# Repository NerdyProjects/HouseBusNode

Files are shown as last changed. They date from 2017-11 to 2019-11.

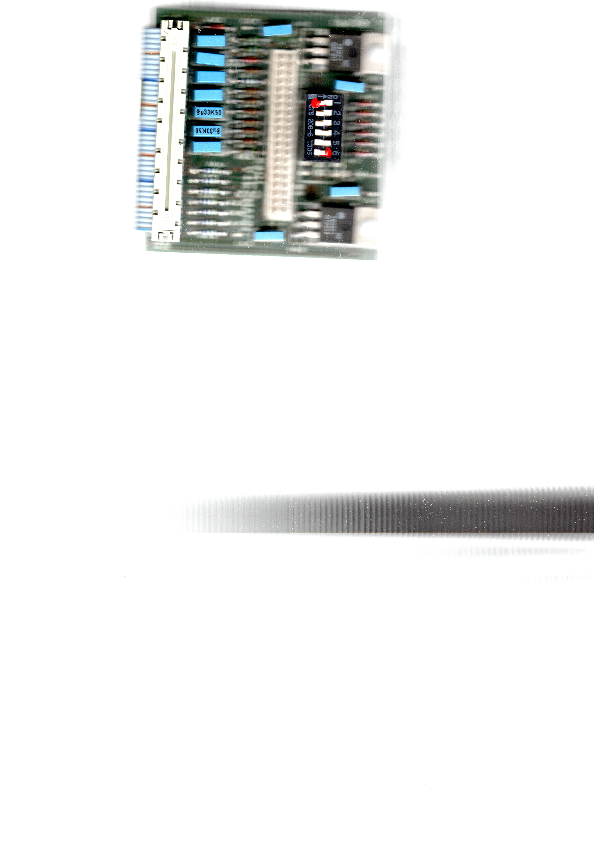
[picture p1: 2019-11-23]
viessmann_trimatik_elektronikbox.jpg

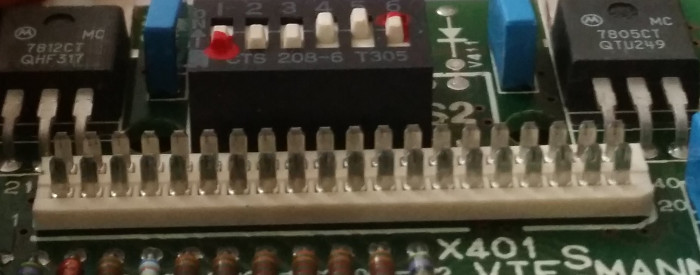
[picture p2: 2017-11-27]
viessmann_stecker.jpg

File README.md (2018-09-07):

# Hausbus Spielerei

## Short introduction

This repository holds hardware and software design for a work in progress house bus system.
It operates using a 4-wire bus using the CAN bus as well as supply of ~10 - 20 V.
It should provide a base for very simple nodes (e.g. sensors, digital actors) as well as more complex nodes (e.g. a heating system controller).

## Background

The system design started in November 2017 when the need of a better heating system controller arose in a housing project in Wurzen, Germany.
The gas heating system, a well overpowered Viessmann Atola controlled by a Viessmann Trimatik MC should be better controlled in light load conditions with options to get it better tuned to the actual needs.
A good heating system needs to be remote controllable as well as take a lot of different control inputs, in best case from every room as well as every radiator and maybe even some valves in between.

Additionally, it is nice to gather statistics about used gas, electricity and water.

When such a system is in place already, it would be great to combine it with other actors and sensors around the house: Doorbell, switches, PIR sensors, dimming of lights (without having to use expensive dimmers or even without standing up from your desk).

## Design implications

The design is driven by a mind that likes to play around with technology, gather statistics and try to optimize the world around.
The design is not meant to be used for things that require absolute reliability or fool-saveness.
The design is not meant to be used in applications or environment where security is needed.
The communication between the nodes happen without any security layer: Every node is able to set any value in any other node, so can everybody tapping into the bus wire.

# Hardware description

## PCB Errata

## Mini-PCB

* Triac T1/T2 (Pin 1/2) need to be exchanged. Easiest to be done by soldering Triac backwards just with Pin 1 and 2 and using a wire for Pin 3.

## Microcontroller

The microcontroller in use is the STM32F072RBT6. It is powered by an ARM Cortex-M0 core with 128 kBytes of flash memory and 16 kBytes of SRAM data memory.

### Compatible boards/projects

There is a list of boards using the same controller.
Because of the broad availability and use of these boards, they might be worth a look for application examples (be it hardware or software).

* STM32F072 Discovery Kit
* STM32 Nucleo-64 / Nucleo-F072RB (Arduino like development board)

## BUS

The CAN-Bus is not meant to operate with long stub lines - but using slew rate control, it is safe to do so.
Following CAN physical layer requirements (TI SLLA270, 01/2008), the maximum stub length should be less than 1/3rd of the critical length, which equals the down-and-back delay of the transition time, which is the longer of the rise or fall times:

| HVD230 Rs | Tplh | Tphl | 1/3 of critical length | max. length @ 250 kBaud | max. length @ 125 kBaud |
| --- | ---- | ---- | --- | --- | --- |
| 0 | 35 ns| 70 ns | 2.3 m (1.1 m) | ~280 m |
| 10k | 65 ns| 130 ns | 4.3 m (2.1 m) | ~282 m |
| 100k | 500 ns| 870 ns | 29 m (16.6 m) | ~208 m |

The max. length is calculated using the HVD230 given tp of ~37 ns, the comparator delay inside the processor is estimated with 10 ns.
The calculation shows, that the effect of slew rate control on bus length is minimal for these speeds.
At a higher speed, the transition delay inside the driver takes up bigger parts of the available time window, which is ~3 us for 250 kBaud.
Also, it is not exactly clear to me why the speed does not matter when calculating the stub lengths, but the given results clearly show, that 100k slew rate control and a 250 kBaud bus is appropriate for usage in a house.
For a normal sized living house, the bus should be fed through each flats hallway to allow each rooms' connection with stubs.
For houses like the housing project where this is designed for, this leads to a bus length of approximately 120m:
Both ends "stub" 30m each, 2 times 3 floors with 3.5 m height (connection just through stubs, as all points are reachable within 30m), 2 times basement to pass to the next building (15m), which sums up to 30+30+2\*3\*3.5+15+15 = 111m

## Power

Each bus node has an on-board step down converter to convert the bus voltage (because of the availabiliy of cheap step downs <24 V) to 3.3 V for the circuit.
Some applications might use the bus power directly, when exact voltage does not matter and current is limited (so the bus is not powered off).
The network should be usable with ~50 nodes that can be power-fed at multiple times in the bus.

The bus cable resistance following the above approximation (120m) and taking 0.4mm/0.13mm² cable (AWG26) as a worst case candidate comes down to ~30 ohms.
Taking a worst case, default active operational current of 50 mA @ 3.3V for 50 nodes (~8 W), as well as a supply of 18 V already results in a current consumption of 450 mA, which would be too big for the given cabling.
Due to this, power consumption of nodes should be kept in mind when deploying them.

A node that is close to a powerful bus power feed can easily use the bus power to drive lighting or a doorbell with 20 W.
It is left to the deployer of the bus system to ensure that the bus voltage drop is taken into account when deploying powerful nodes.

## Board pin mapping (Board: Hausspielerei 11/2017)

Please always consider the schematics for details.
Still, the following table describes the available connectors, suggested use cases and possible use cases.

### Analog IO

Analog pins on this board are named with their corresponding usage on the Viessmann Trimatik-MC.
All of the pins in the list feature strong pullup resistors, that are all switched by /PA0 (Q1) to AVCC (3,3V)

| pin name | controller pin | available hardware | possible alternative functions |
| --- | --- | --- | --- |
| IN\_ATS  | PA1 | series 0805, 2x 0805 to GND | USART2\_RTS / RS422 DE / RS485 DE, USART4\_RX |
| IN\_KTS  | PA2 | 0805 to GND | USART2\_TX / RS422 TX / RS485 TX, COMP1\_INP, COMP2\_INM, COMP2\_OUT |
| IN\_VTS  | PA3 | 0805 to GND | USART2\_RX / RS422 RX / RS485 RX, COMP2\_INP |
| IN\_STS  | PA4 | 0805 to GND | COMP2\_INM, COMP1\_INM, DAC_OUT1 |
| IN\_FB1  | PA5 | 0805 to GND | COMP1\_INM, COMP2\_INM, DAC_OUT2, SPI1\_SCK |  
| IN\_FB2  | PA6 | 0805 to GND | COMP1\_OUT, SPI1\_MISO |
| LED_A | PA7 | series 0805 | COMP2\_OUT, SPI1\_MOSI |

### Connectors

| Connector  | Pins | controller pins | primary purpose | alternative purposes | conflicting with |
| --- | ---  | --- | --- | --- | ---  |
| J12, J13 | VCC GND CANH CANL | | Power (5-24V), bus + passthrough | | No conflicts |
| SMPS (J3)  | NC Vin(J12/13 Vcc) GND 3,3V | | SMPS module for 3,3V power supply | | No conflicts |
| RS485 (J17)| GND A B 3,3V | PA1, PA2, PA3 | RS485/RS422 connection to sub boards | By bridging appropriate Pins in U1, it can be used as USART2 TX/RX/RTS or Analog inputs | DE: J9 / IN\_ATS |
| J9 | IN\_FB1 3,3V GND IN\_ATS | PA5, PA1 | digital/analog input for hall sensor module | | IN\_ATS: RS485 DE |
| D1 (LED A) | GND LED\_A | PA7 | General purpose LED | IO, Analog comparator output, SPI MOSI | No conflicts |
| J16 (230V) | SW2-A SW2-B SW1-A SW1-B | PB0 (SW2), PB11 (SW1) | Opto triac + triac controlled power switch for 230V AC | Switching, Dimming, GPIO | No conflicts |
| J6 (DIN4..1) | DIN4 DIN3 DIN2 DIN1 | PB1 PB2 PB10 PF1 | GPIO | DIN4: Analog In | No conflicts |
| D2 (LED B) | GND LED\_B | PA15 | General purpose LED | IO, USART2\_RX | No conflicts |
| J5 (GND) | GND GND GND GND | | | |
| J14 | SW3 GND SW4 GND | PA8 PB3 | Open drain load switch, TIM1\_CH1, TIM2\_CH2 | 4: SPI1\_SCK | No conflicts |
| J15 | SW1 GND SW2 GND | PB4 PB5 | Open drain load switch, TIM3\_CH1, TIM3\_CH2 | SPI1\_MISO SPI1\_MOSI | No conflicts |
| J10 (I2C)  | 3,3V GND SCL SDA | PB6 PB7 | I2C | USART1\_TX, USART1\_RX | Shared I2C bus with J8, EEPROM |
| J8 (I2C) | 3,3V GND SCL SDA | PB6 PB7 | I2C | USART1\_TX, USART1\_RX | Shared I2C bus with J10, EEPROM |
| J4 (BOOT)  | GND BOOT 3,3V | BOOT | bootmode selection (1-2: FLASH, 2-3: system rom bootloader) | | |
| J7 (SWD) | SWDIO SWDCLK GND | PA13 PA14 | SWD debug / programming connector | | No conflicts |
| J11 (USB)  | DP DM GND | PA12 PA11 | USB connection | COMP2\_OUT COMP1\_OUT | No conflicts |
| J18 (UART) | TX RX GND | PA9 PA10 | USART1\_TX USART1\_RX | TIM1\_CH2 TIM1\_CH3 | No conflicts |
| J1/J2 | see schematics | see schematics  | Viessmann Trimatik MC X1 | use signals individually, see schematics |

A lot of the connectors share the same physical pins.
Especially the Trimatik-MC connector shares pins with almost all other connectors, so it is not explicitly listed in the above table.
Some functionality of the Trimatik-MC might be disabled by cutting pins (or checking for electrical compatibility) - otherwise the following connectors are conflict free here as well:

  * SWD
  * I2C
  * CAN
  * J15 / Open drain switches 1, 2

When keeping minimum Trimatik-MC controller features, following connectors can never be used:
  
  * USB
  * J17 RS422/RS485
  * 230V SW1 (only by cutting J1 Pin12)

Please have a look at the schematics when wanting to use conflicting connectors at the same time, there might be options :-)

# Software description

## USB CAN Adapter firmware
The hardware should be compatible to the [CandleLight](https://github.com/HubertD/candleLight) project, so you can just use the [CandleLight Firmware](https://github.com/HubertD/candleLight_fw).
Just one change: This hardware does not supply any external oscillator, so the firmware might need to be adapted.
This firmware has not been tested.

## Ideas

## RTOS
The simplicity of each individual node does not require an operating system.
For simplicity, ease of use and improval of robustness, a simple task scheduler is highly recommended.

[ChibiOs](http://www.chibios.org) provides a simple, high performance, low footprint kernel (ChibiOS/RT) and a useful hardware abstraction layer (HAL).
Both are well tested for the used Cortex M0 controller.
The HAL provides support for almost all components of the controller:

* USB (including USB-CDC for serial connections)
* GPIO
* ADC (including using DMA transfers)
* CAN
* Timers (including PWM outputs)
* I2C

An introduction document is available: [ChibiOS/RT3.0 The ultimate Guide](http://chibios.org/dokuwiki/doku.php?id=chibios:book:start)

### Encryption / signature
Although not necessary in this project, I am interested in using a crypto library.
http://kmackay.ca/micro-ecc/ seems nice to use on our Cortex M0.

### CAN protocol
  Libuavcan CAN library (Cortex M0: 30 kBytes flash, 6 kBytes ram) seems nice as it supports broadcast messages as well as unicast transfers.

  Its DSL allows building arbitrary messages for different data to transmit.
  All devices need to agree on the subset of packets they want to use (easy, as otherwise they could not use them anyway).

  There is no additional network management layer necessary.

  Tooling seems good, development stable.

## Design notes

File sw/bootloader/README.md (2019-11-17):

# Build and program bootloader:

First, build:
```
make
```

Connect your target to your programmer, ST-LINK V2 in our case(3.3V Voltage, Ground, SWDIO, SWCLK). 

Run `./flash.sh`. 

In case something didn't work, read `flash.sh` and `flash.gdb` for detailed commands and execute them manually.

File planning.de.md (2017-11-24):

# Planung Heizungssteuerung / Elektronikbox Ersatz für Viessmann Trimatik-MC

## Konzept

Zur Einfachheit wird das bestehende Konzept der Trimatik-MC beibehalten, es wird lediglich die Elektronikbox ausgetauscht.
Dies hat mehrere Vorteile:
  * Bei Schornsteinfeger und Wartung kann das Original eingesetzt werden
  * Alle Anschlüsse sind bereits vorhanden
  * Eine Stromversorgung ist bereits vorhanden

Die hier entwickelte Schaltung soll zudem in ein Hausbus System mittels CAN-Bus eingebaut werden können.
Optional soll der Platinenentwurf auch weitere, einfache Busknoten ermöglichen:
  * Temperatursensor (Analog)
  * Temperatur/Feuchtesensor (Digital/I2C)
  * Digital-IO (z.B. Klingeltaster, Türöffner, Lichtschalter)
  * Lichtsteuerung (DC-PWM, AC-Triac)
  * weitere I2C Hardware (Display, IO-Expander, Keypad, ...)
  * Anbindung an lokale Knoten ("Busadapter") über TTL-UART oder 2-Draht halbduplex RS422/RS485/DMX

Die Bestückung bestimmt dabei die Möglichkeiten, das Platinendesign soll möglichst vielseitig sein.

## Komponenten

  * 2x 4 pin Bus-Stecker (CAN H/L, Vcc (5..24V, GND)
  * STM32F072C8T6 /072CBT6 Mikrocontroller, LQFP-48 (64 kByte flash, 16 kByte Ram) / 128 kByte flash
  * AT24C64 EEPROM (I2C)
  * 3.3V CAN Bus Transceiver sn65hvd230 (Rs ~47k nach GND, an µC für Standby Control)
  * SWD Anschluss
  * Nutzung eines Step-Down Moduls zum Auflöten/Aufstecken von <24V -> 3.3V
  * USB-Device (optional - wofür könnte das sinnvoll sein?)
  * KF120 2.54mm Rastermaß Anschlussklemmen (6,3mm tief)
  * options:
    * BME280 temp/pressure/humidity sensor (I2C, 3.3V: 3.3V GND SCL SDA (2.54mm)) -> 2x I2C Header
    * KY-024 hall sensor (3.3V, digital/analog output: DO 3.3V GND AO (2.54mm)) -> 1x Analog/Digital Header
    * RS422/RS485 communication (ISL83483 driver; e.g. to connect modified sparmatic zero radiator driver or other local nodes)
    * 4 Open Drain Schaltausgänge, Beispiel: Klingel, Licht;Optionen für SOT223 und TO220 N-Fets, mit und ohne Freilauf auf Board
      * FDT86113LZ SOT223 100V/~2A
      * IRF3708 TO220 30V /~15A
    * 4 Digitalein/ausgänge mit optionalem Schutz-Reihenwiderstand direkt an Controller
    * 2 Status LEDs
    * 40 pin Viessmann-Stecker
      * 6 Analogeingänge mit (schaltbaren) Pullups (für ~500 Ohm PTC Sensor) (ADC 0.. Vdda, 12bit, no oversampling)
      * 6 CMOS Schaltausgänge, 3,3V (Relais)
      * Nutzung der 6x16 Stufen Drehschalter auf Schalterplatine über 3x4 Matrix
      * Nutzung der LEDs der Frontplatte

## Software
  
  * Libuavcan CAN library (30 kBytes flash, 6 kBytes ram)

Schaltregler breakouts (11mmx20mm):
EN IN+ GND VO
(2.54mm Raster, Winkel/gerade pinheader)

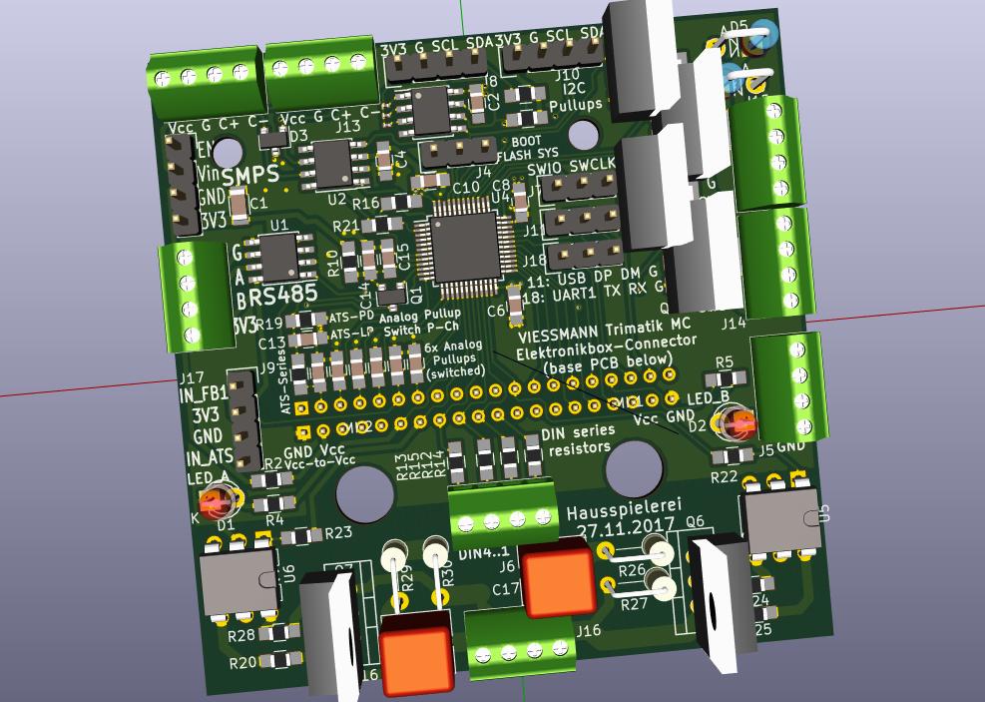
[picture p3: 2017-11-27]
pcb/base_heating.jpg

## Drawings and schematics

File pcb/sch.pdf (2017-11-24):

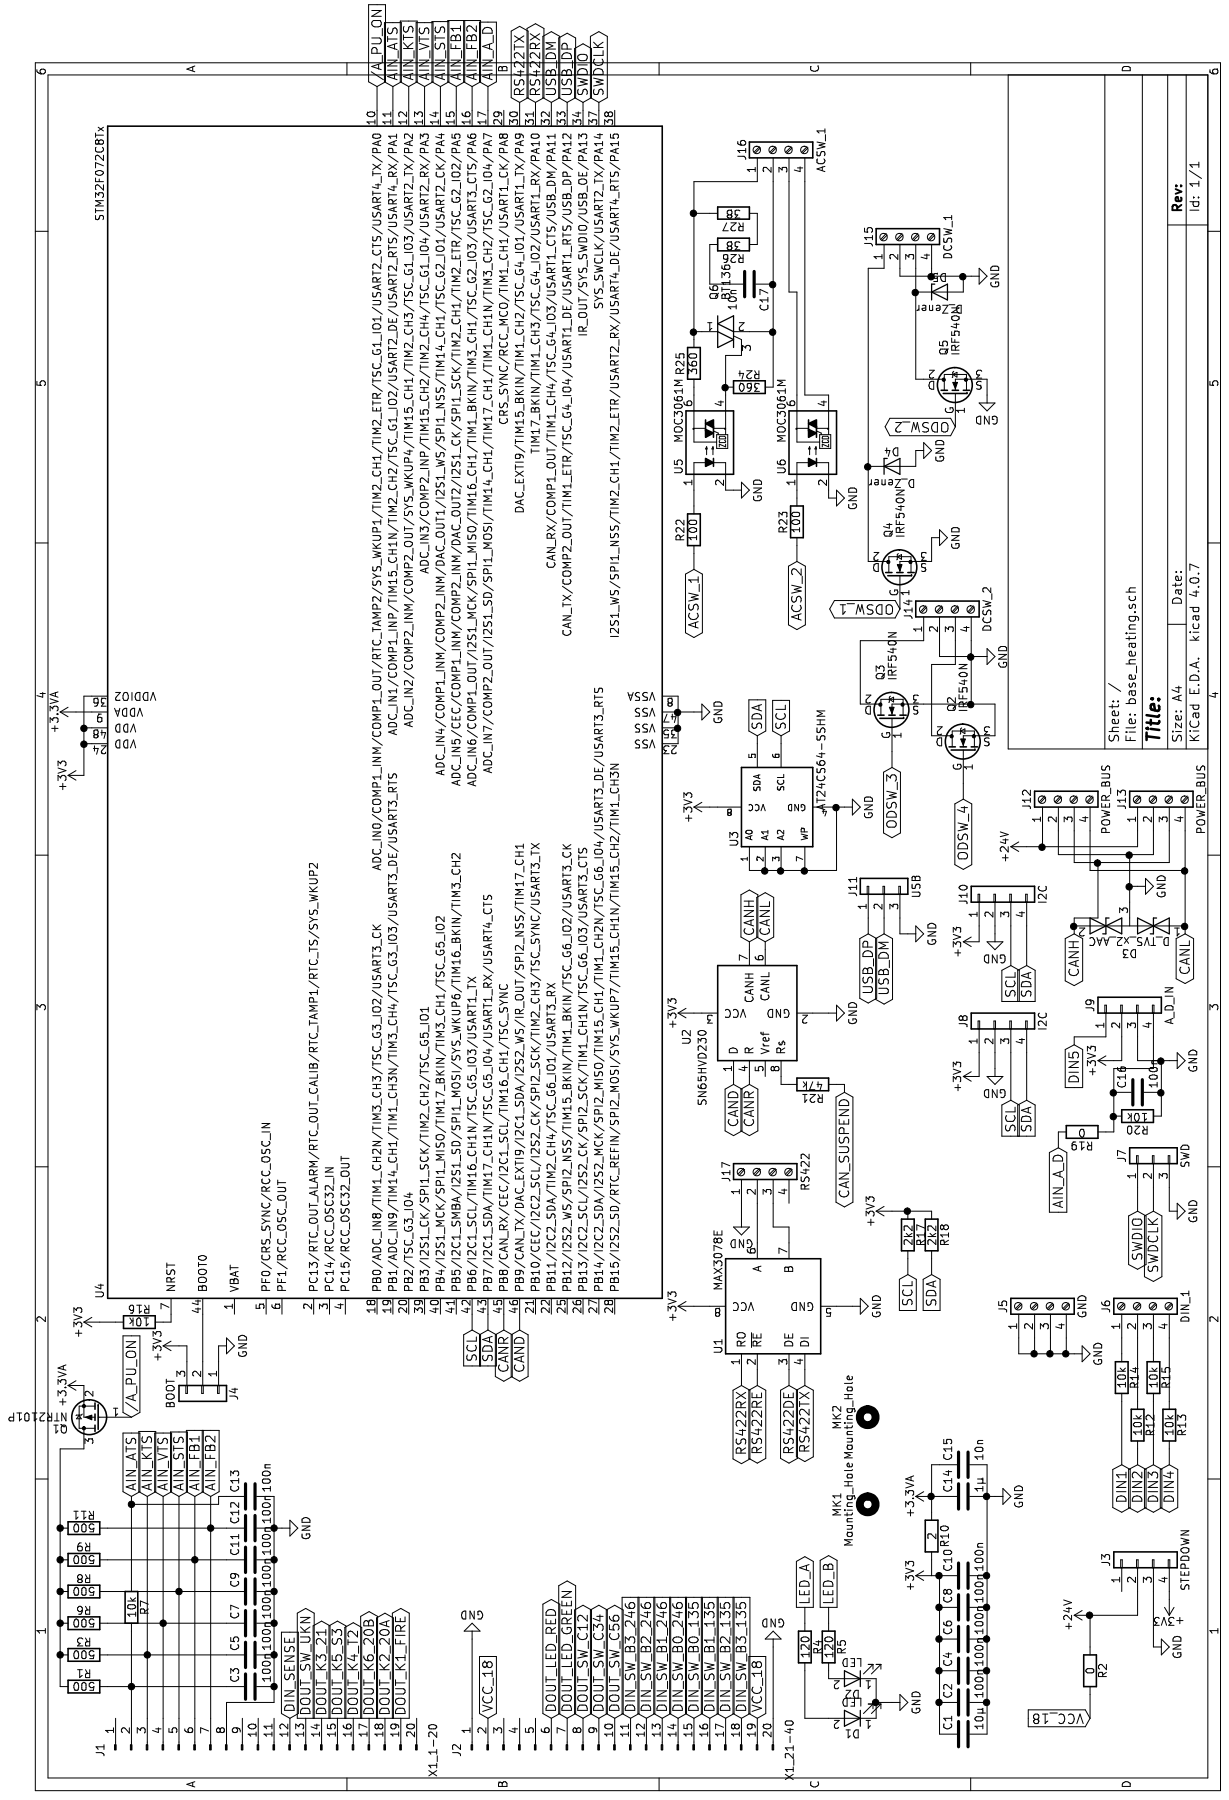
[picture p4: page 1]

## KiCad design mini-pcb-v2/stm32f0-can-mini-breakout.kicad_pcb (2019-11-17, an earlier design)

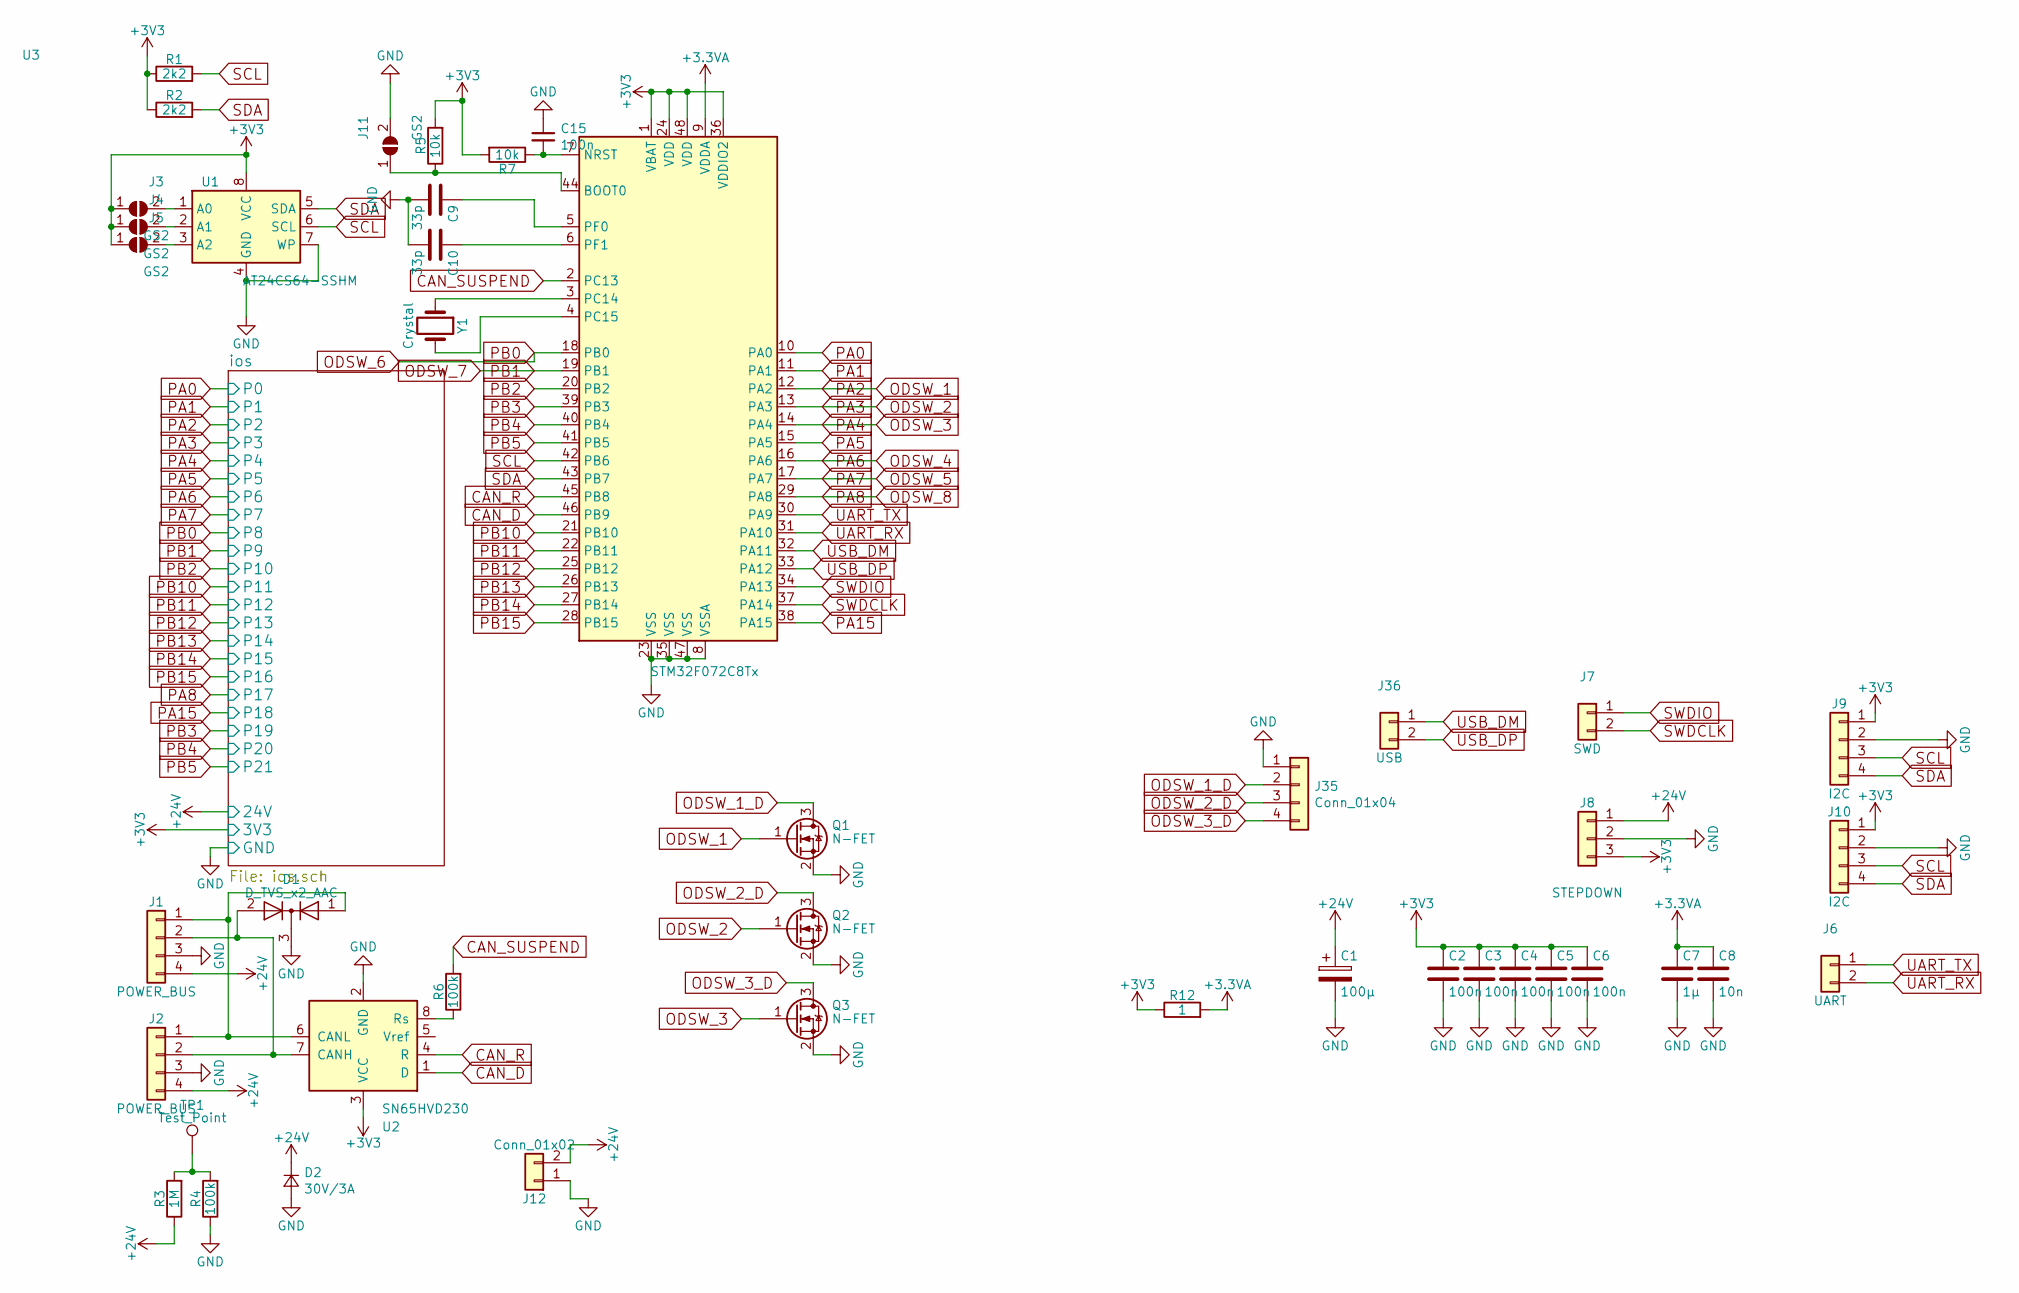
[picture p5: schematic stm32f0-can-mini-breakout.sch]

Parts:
C1: 100µ; CP_Radial_D6.3mm_P2.50mm
C2, C3, C4, C5, C6, C15: 100n; C_0603_1608Metric_Pad1.05x0.95mm_HandSolder
C7: 1µ; C_0805_2012Metric_Pad1.15x1.40mm_HandSolder
C8: 10n; C_0603_1608Metric_Pad1.05x0.95mm_HandSolder
C9, C10: 33p; C_0805_2012Metric_Pad1.15x1.40mm_HandSolder
D1: D_TVS_x2_AAC; SOT-23_Handsoldering
D2: 30V/3A; D_SMB
J1, J2: POWER_BUS; JST_XH_B4B-XH-A_1x04_P2.50mm_Vertical
J3, J4, J5: GS2; R_0402_1005Metric
J6: UART; PinHeader_1x02_P2.54mm_Vertical
J7: SWD; PinHeader_1x02_P2.54mm_Vertical
J8: STEPDOWN; PinHeader_1x03_P2.54mm_Vertical
J9, J10: I2C; PinHeader_1x04_P2.54mm_Vertical
J11: GS2; SolderJumper-2_P1.3mm_Open_RoundedPad1.0x1.5mm
J12: Conn_01x02; TerminalBlock_Phoenix_PT-1,5-2-3.5-H_1x02_P3.50mm_Horizontal
J35: Conn_01x04; PinHeader_1x04_P2.54mm_Vertical
J36: USB; PinHeader_1x02_P2.54mm_Vertical
Q1, Q2, Q3: N-FET; SOT-23
R1, R2: 2k2; R_0603_1608Metric_Pad1.05x0.95mm_HandSolder
R3: 1M; R_0805_2012Metric_Pad1.15x1.40mm_HandSolder
R4, R6: 100k; R_0603_1608Metric_Pad1.05x0.95mm_HandSolder
R5, R7: 10k; R_0603_1608Metric_Pad1.05x0.95mm_HandSolder
R12: 1; R_0805_2012Metric_Pad1.15x1.40mm_HandSolder
TP1: Test_Point; Pin_D0.7mm_L6.5mm_W1.8mm_FlatFork
U1: AT24CS64-SSHM; SOIC-8_3.9x4.9mm_P1.27mm
U2: SN65HVD230; SOIC-8_3.9x4.9mm_P1.27mm
U3: STM32F072C8Tx; LQFP-48_7x7mm_P0.5mm
Y1: Crystal; Crystal_C38-LF_D3.0mm_L8.0mm_Vertical

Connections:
+3.3VA: C7.1, C8.1, R12.2, U3.9 (VDDA)
+3V3: C2.1, C3.1, C4.1, C5.1, C6.1, J3.1 (A), J4.1 (A), J5.1 (A), J8.3, J9.1, J10.1, R1.1, R2.1, R5.2, R7.2, R12.1, U1.8 (VCC), U2.3 (VCC), U3.1 (VBAT), U3.24 (VDD), U3.36 (VDDIO2), U3.48 (VDD); also elsewhere on the board
+24V: C1.1, D2.1 (K), J1.4, J2.4, J8.1, J12.2, R3.1; also elsewhere on the board
CAN_D: U2.1 (D), U3.46 (PB9)
CAN_R: U2.4 (R), U3.45 (PB8)
CAN_SUSPEND: R6.2, U3.2 (PC13)
GND: C1.2, C2.2, C3.2, C4.2, C5.2, C6.2, C7.2, C8.2, C9.2, C10.2, C15.1, D1.3 (K), D2.2 (A), J1.3, J2.3, J8.2, J9.2, J10.2, J11.2 (B), J12.1, J35.1, Q1.2 (S), Q2.2 (S), Q3.2 (S), R4.1, U1.4 (GND), U1.7 (WP), U2.2 (GND), U3.8 (VSSA), U3.23 (VSS), U3.35 (VSS), U3.47 (VSS); also elsewhere on the board
unnamed: C9.1, U3.5 (PF0)
unnamed: C10.1, U3.6 (PF1)
unnamed: C15.2, R7.1, U3.7 (NRST)
unnamed: D1.1 (A), J1.1, J2.1, U2.6 (CANL)
unnamed: D1.2 (A), J1.2, J2.2, U2.7 (CANH)
unnamed: J3.2 (B), U1.1 (A0)
unnamed: J4.2 (B), U1.2 (A1)
unnamed: J5.2 (B), U1.3 (A2)
unnamed: J11.1 (A), R5.1, U3.44 (BOOT0)
unnamed: R3.2, R4.2, TP1.1
unnamed: R6.1, U2.8 (Rs)
unnamed: U3.3 (PC14), Y1.1
unnamed: U3.4 (PC15), Y1.2
ODSW_1: Q1.1 (G), U3.12 (PA2); also elsewhere on the board
ODSW_1_D: J35.2, Q1.3 (D)
ODSW_2: Q2.1 (G), U3.13 (PA3); also elsewhere on the board
ODSW_2_D: J35.3, Q2.3 (D)
ODSW_3: Q3.1 (G), U3.14 (PA4); also elsewhere on the board
ODSW_3_D: J35.4, Q3.3 (D)
ODSW_4: U3.16 (PA6); also elsewhere on the board
ODSW_5: U3.17 (PA7); also elsewhere on the board
ODSW_6: U3.18 (PB0); also elsewhere on the board
ODSW_7: U3.19 (PB1); also elsewhere on the board
ODSW_8: U3.29 (PA8); also elsewhere on the board
PA0: U3.10 (PA0); also elsewhere on the board
PA1: U3.11 (PA1); also elsewhere on the board
PA5: U3.15 (PA5); also elsewhere on the board
PA15: U3.38 (PA15); also elsewhere on the board
PB2: U3.20 (PB2); also elsewhere on the board
PB3: U3.39 (PB3); also elsewhere on the board
PB4: U3.40 (PB4); also elsewhere on the board
PB5: U3.41 (PB5); also elsewhere on the board
PB10: U3.21 (PB10); also elsewhere on the board
PB11: U3.22 (PB11); also elsewhere on the board
PB12: U3.25 (PB12); also elsewhere on the board
PB13: U3.26 (PB13); also elsewhere on the board
PB14: U3.27 (PB14); also elsewhere on the board
PB15: U3.28 (PB15); also elsewhere on the board
SCL: J9.3, J10.3, R1.2, U1.6 (SCL), U3.42 (PB6)
SDA: J9.4, J10.4, R2.2, U1.5 (SDA), U3.43 (PB7)
SWDCLK: J7.2, U3.37 (PA14)
SWDIO: J7.1, U3.34 (PA13)
UART_RX: J6.2, U3.31 (PA10)
UART_TX: J6.1, U3.30 (PA9)
USB_DM: J36.1, U3.32 (PA11)
USB_DP: J36.2, U3.33 (PA12)

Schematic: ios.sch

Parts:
C11, C12, C13, C14: 33n; C_Rect_L18.0mm_W6.0mm_P15.00mm_FKS3_FKP3
J13, J14, J15, J16, J17, J18, J26, J27, J28, J30, J31, J32, J33, J37, J38: Conn_01x09; Pin_Header_Straight_1x09_Pitch2.54mm
J19, J20, J21: Conn_01x08; Pin_Header_Straight_1x08_Pitch2.54mm
J22, J23, J24, J25, J39, J40, J43, J44, J45: Conn_01x05; Pin_Header_Straight_1x05_Pitch2.54mm
J29, J34, J41: Conn_01x07; Pin_Header_Straight_1x07_Pitch2.54mm
J46, J47, J48, J49: Screw_Terminal_01x02; TerminalBlock_Phoenix_PT-3.5mm_2pol
Q9, Q10, Q11, Q12: BT138-800; TO-220_Neutral123_Vertical
R13, R15, R17, R19: 360; R_0805
R14, R16, R18, R20: 330; R_0805
R21, R22, R23, R24: 66; R_Axial_DIN0207_L6.3mm_D2.5mm_P15.24mm_Horizontal
RV1, RV2, RV3, RV4: Varistor; RV_Disc_D15.5_W4.2_P7.5
U4, U5, U6, U7: MOC3063M; DIP-6_W7.62mm

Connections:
+3V3: J27.1, J27.2, J27.3, J27.4, J27.5, J27.6, J27.7, J27.8, J27.9; also elsewhere on the board
+24V: J37.1, J37.2, J37.3, J37.4, J37.5, J37.6, J37.7, J37.8, J37.9; also elsewhere on the board
GND: J25.1, J25.2, J25.3, J25.4, J25.5, J29.1, J38.1, J38.2, J38.3, J38.4, J38.5, J38.6, J38.7, J38.8, J38.9, U4.2, U5.2, U6.2, U7.2; also elsewhere on the board
unnamed: C11.1, R21.2
unnamed: C11.2, J46.1, Q9.1 (A1), R14.1, RV1.2
unnamed: C12.1, R22.2
unnamed: C12.2, J47.1, Q10.1 (A1), R16.1, RV2.2
unnamed: C13.1, J48.2, Q11.1 (A1), R20.1, RV3.2
unnamed: C13.2, R23.2
unnamed: C14.1, J49.2, Q12.1 (A1), R18.1, RV4.2
unnamed: C14.2, R24.2
unnamed: J46.2, Q9.2 (A2), R13.1, R21.1, RV1.1
unnamed: J47.2, Q10.2 (A2), R15.1, R22.1, RV2.1
unnamed: J48.1, Q11.2 (A2), R19.1, R23.1, RV3.1
unnamed: J49.1, Q12.2 (A2), R17.1, R24.1, RV4.1
unnamed: Q9.3 (G), R14.2, U4.4
unnamed: Q10.3 (G), R16.2, U5.4
unnamed: Q11.3 (G), R20.2, U7.4
unnamed: Q12.3 (G), R18.2, U6.4
unnamed: R13.2, U4.6
unnamed: R15.2, U5.6
unnamed: R17.2, U6.6
unnamed: R19.2, U7.6
ODSW_1: J15.1; also elsewhere on the board
ODSW_2: J16.1; also elsewhere on the board
ODSW_3: J17.1; also elsewhere on the board
ODSW_4: J19.2; also elsewhere on the board
ODSW_5: J19.1; also elsewhere on the board
ODSW_6: J20.2; also elsewhere on the board
ODSW_7: J20.1; also elsewhere on the board
ODSW_8: J30.1; also elsewhere on the board
PA0: J13.1; also elsewhere on the board
PA1: J14.1; also elsewhere on the board
PA5: J18.1; also elsewhere on the board
PA15: J31.1; also elsewhere on the board
PB2: J21.1; also elsewhere on the board
PB3: J32.1; also elsewhere on the board
PB4: J33.1; also elsewhere on the board
PB5: J33.2; also elsewhere on the board
PB10: J22.1; also elsewhere on the board
PB11: J23.1; also elsewhere on the board
PB12: J26.2; also elsewhere on the board
PB13: J26.1; also elsewhere on the board
PB14: J28.2; also elsewhere on the board
PB15: J28.1; also elsewhere on the board

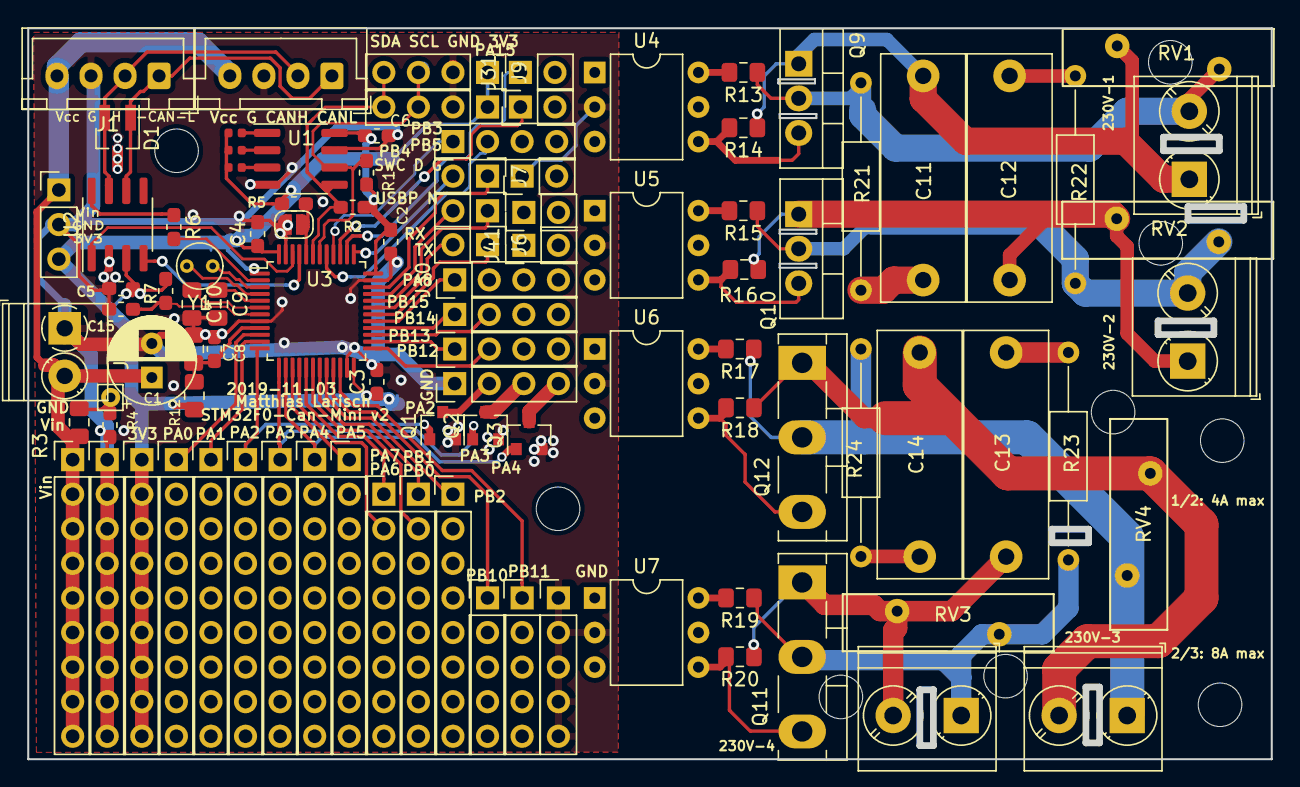
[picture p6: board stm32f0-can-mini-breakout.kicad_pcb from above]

Board: 2 copper layers, 91.4 x 53.7 mm, 99 parts (1 on the bottom side), 73 nets.

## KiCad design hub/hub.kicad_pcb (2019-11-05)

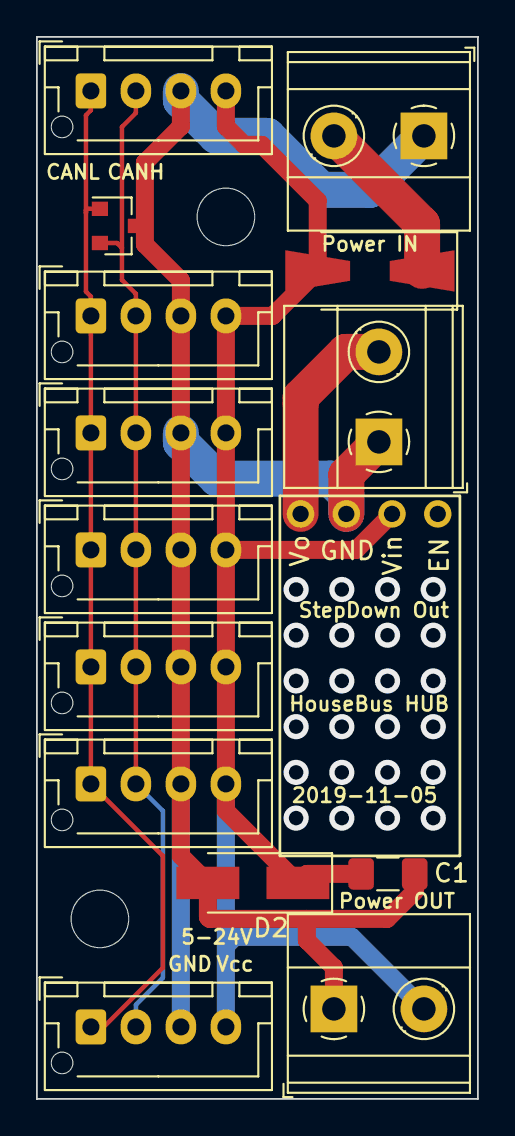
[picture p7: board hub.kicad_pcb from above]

Board: 2 copper layers, 24.5 x 59.0 mm, 17 parts (0 on the bottom side), 6 nets.

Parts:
C1: 10µ; C_1206_3216Metric_Pad1.42x1.75mm_HandSolder
D1: SK34; D_SMA-SMB_Universal_Handsoldering
D2: D_TVS; D_SMA_Handsoldering
D3: D_TVS_x2_AAC; SOT-23
H1, H2: MountingHole; MountingHole_3.2mm_M3
J1, J2, J3, J4, J5, J6, J9: Conn_01x04; JST_XH_B4B-XH-AM_1x04_P2.50mm_Vertical
J7: Power IN; TerminalBlock_Phoenix_MKDS-1,5-2_1x02_P5.00mm_Horizontal
J8, J10: Power OUT; TerminalBlock_Phoenix_MKDS-1,5-2_1x02_P5.00mm_Horizontal
U1: MP2315-Mini-Module; MP2315-Mini

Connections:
CANH: D3.2, J1.2, J2.2, J3.2, J4.2, J5.2, J6.2, J9.2
CANL: D3.1, J1.1, J2.1, J3.1, J4.1, J5.1, J6.1, J9.1
GND: C1.2, D2.2, D3.3, J1.3, J2.3, J3.3, J4.3, J5.3, J6.3, J7.1, J8.1, J9.3, J10.1, U1.2
unnamed: D1.1, J7.2
unnamed: J10.2, U1.1
VCC: C1.1, D1.2, D2.1, J1.4, J2.4, J3.4, J4.4, J5.4, J6.4, J8.2, J9.4, U1.3

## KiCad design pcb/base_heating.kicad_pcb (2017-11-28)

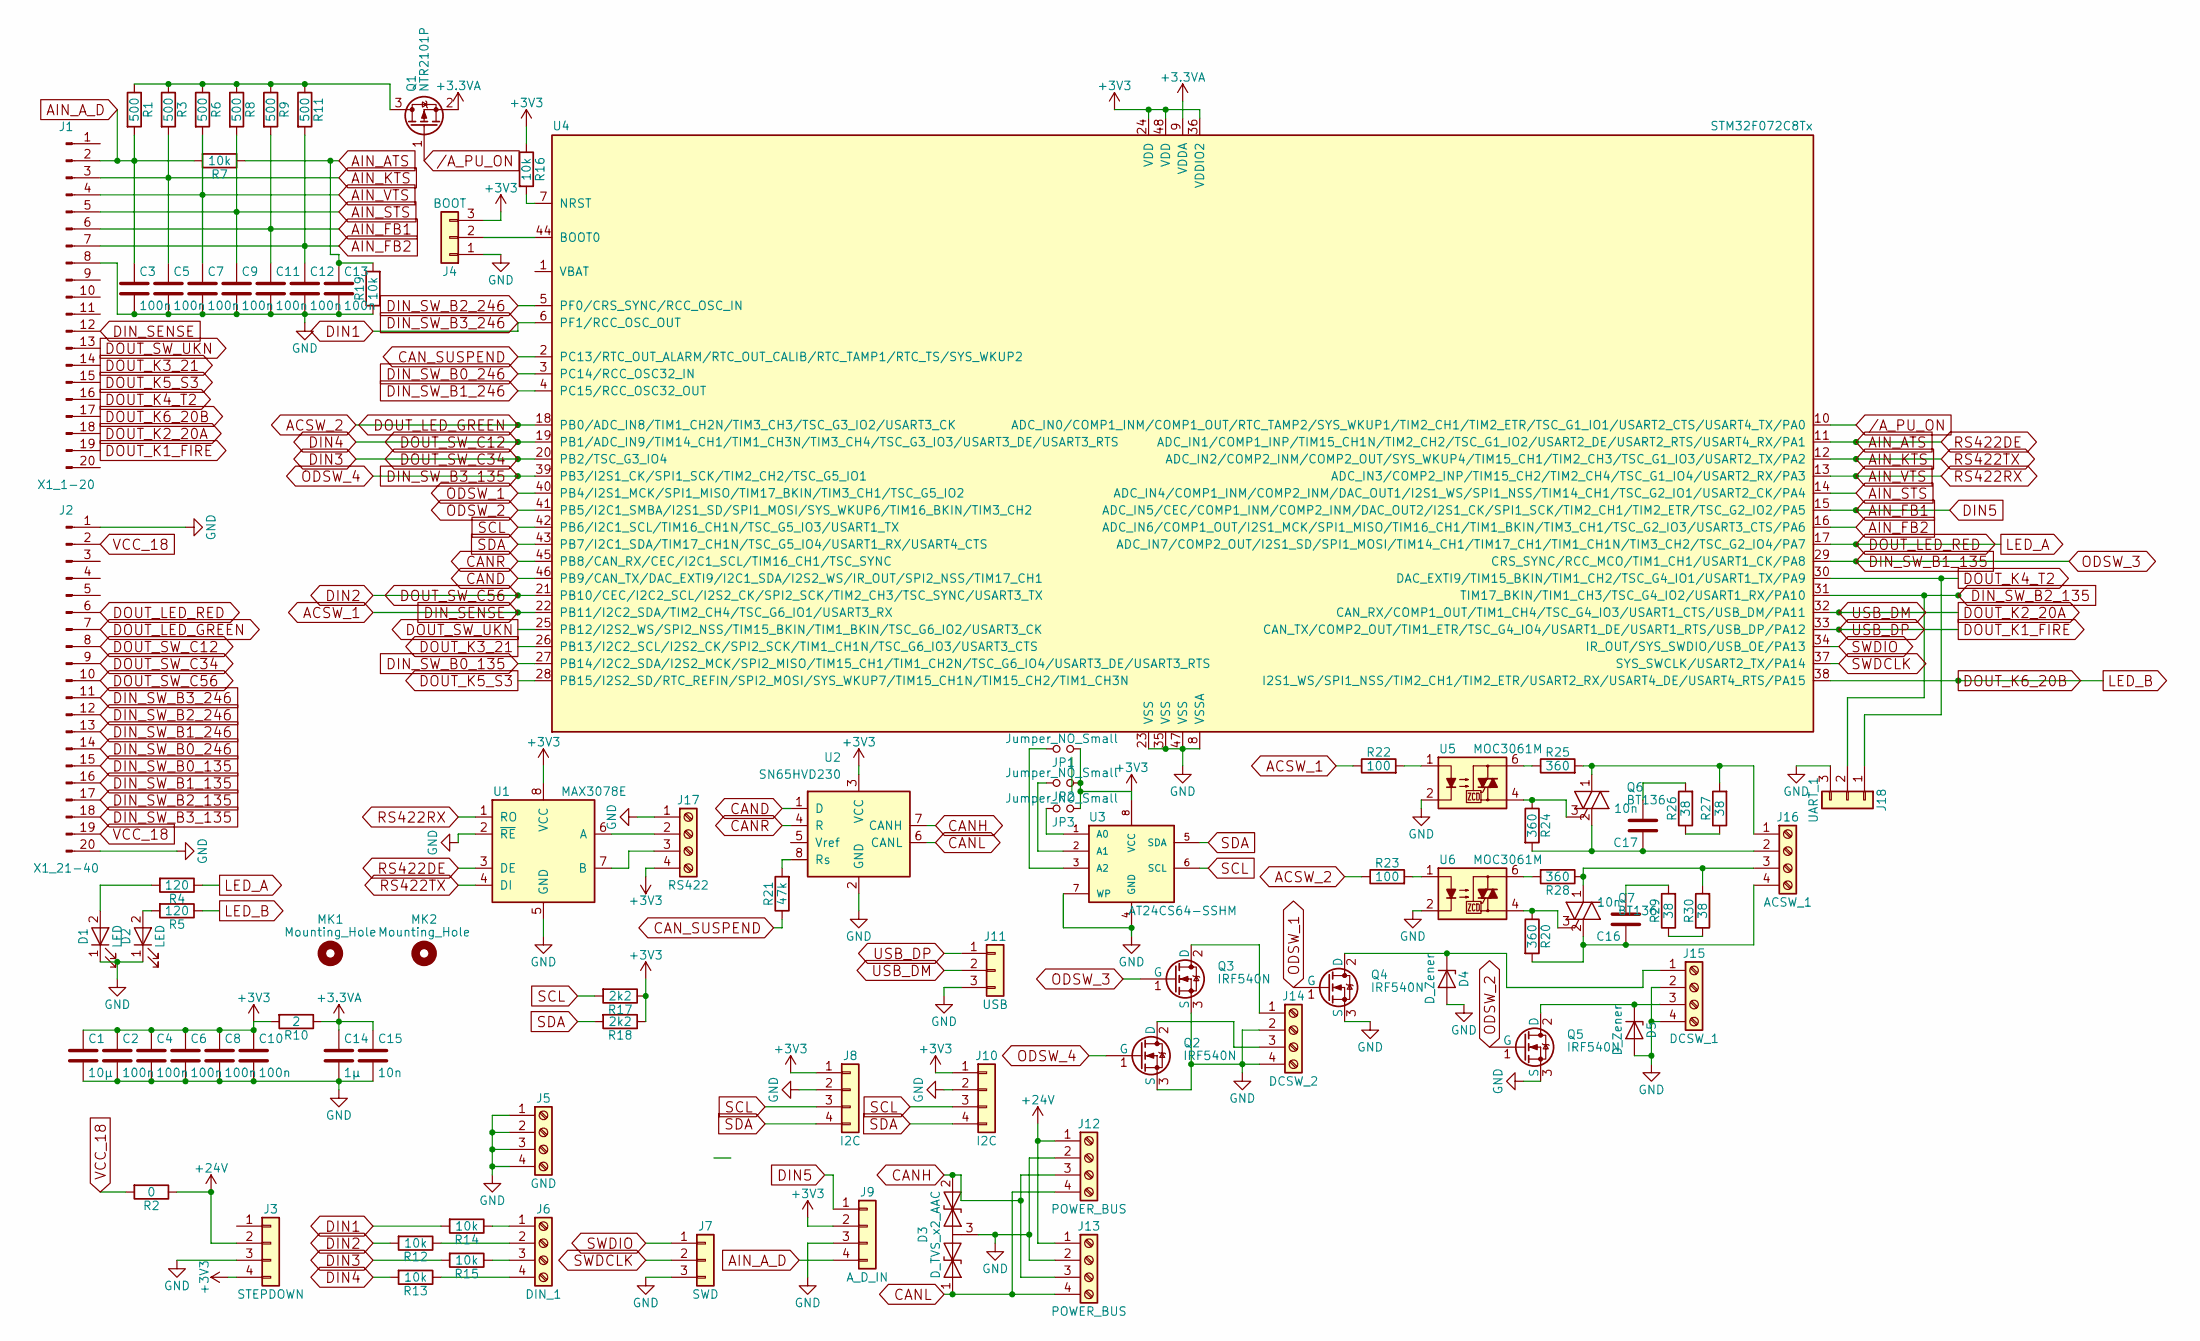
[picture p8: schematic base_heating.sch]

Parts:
C1: 10µ; C_1206
C2, C3, C4, C5, C6, C7, C8, C9, C10, C11, C12, C13: 100n; C_0805_HandSoldering
C14: 1µ; C_0805_HandSoldering
C15: 10n; C_0805_HandSoldering
C16, C17: 10n; C_Rect_L7.0mm_W6.5mm_P5.00mm
D1, D2: LED; LED-3MM
D3: D_TVS_x2_AAC; SOT-23
D4, D5: D_Zener; Diode_DO-41_SOD81_Vertical_AnodeUp
J1: X1_1-20; Pin_Header_Straight_1x20_Pitch2.00mm
J2: X1_21-40; Pin_Header_Straight_1x20_Pitch2.00mm
J3: STEPDOWN; Pin_Header_Straight_1x04
J4: BOOT; Pin_Header_Straight_1x03
J5: GND; TerminalBlock_Pheonix_MPT-2.54mm_4pol
J6: DIN_1; TerminalBlock_Pheonix_MPT-2.54mm_4pol
J7: SWD; Pin_Header_Straight_1x03
J8, J10: I2C; Pin_Header_Straight_1x04
J9: A_D_IN; Pin_Header_Straight_1x04
J11: USB; Pin_Header_Straight_1x03
J12, J13: POWER_BUS; TerminalBlock_Pheonix_MPT-2.54mm_4pol
J14: DCSW_2; TerminalBlock_Pheonix_MPT-2.54mm_4pol
J15: DCSW_1; TerminalBlock_Pheonix_MPT-2.54mm_4pol
J16: ACSW_1; TerminalBlock_Pheonix_MPT-2.54mm_4pol
J17: RS422; TerminalBlock_Pheonix_MPT-2.54mm_4pol
J18: UART_1; Pin_Header_Straight_1x03
JP1, JP2, JP3: Jumper_NO_Small; C_0201_NoSilk
MK1, MK2: Mounting_Hole; MountingHole_6mm
Q1: NTR2101P; SOT-23
Q2, Q3, Q4, Q5: IRF540N; SOT-223-3_TabPin2
Q6, Q7: BT136; TO-220_Neutral123_Vertical
R1, R3, R6, R8, R9, R11: 500; R_0805_HandSoldering
R2: 0; R_0805_HandSoldering
R4, R5: 120; R_0805_HandSoldering
R7, R12, R13, R14, R15, R16, R19: 10k; R_0805_HandSoldering
R10: 2; R_0805_HandSoldering
R17, R18: 2k2; R_0805_HandSoldering
R20, R24, R25, R28: 360; R_0805_HandSoldering
R21: 47k; R_0805_HandSoldering
R22, R23: 100; R_0805_HandSoldering
R26, R27, R29, R30: 38; R_Axial_DIN0207_L6.3mm_D2.5mm_P5.08mm_Vertical
U1: MAX3078E; SOIC-8_3.9x4.9mm_Pitch1.27mm
U2: SN65HVD230; SOIC-8_3.9x4.9mm_Pitch1.27mm
U3: AT24CS64-SSHM; SOIC-8_3.9x4.9mm_Pitch1.27mm
U4: STM32F072C8Tx; LQFP-48_7x7mm_Pitch0.5mm
U5, U6: MOC3061M; DIP-6_W7.62mm

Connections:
+3.3VA: C14.1, C15.1, Q1.2 (S), R10.1, U4.9 (VDDA)
+3V3: C1.1, C2.1, C4.1, C6.1, C8.1, C10.1, J3.4, J4.3, J8.1, J9.2, J10.1, J17.4, JP1.1, JP2.1, JP3.1, R10.2, R16.1, R17.1, R18.1, U1.8 (VCC), U2.3 (VCC), U3.8 (VCC), U4.24 (VDD), U4.36 (VDDIO2), U4.48 (VDD)
+24V: J3.2, J12.1, J13.1, R2.1
/A_PU_ON: Q1.1 (G), U4.10 (ADC_IN0/COMP1_INM/COMP1_OUT/RTC_TAMP2/S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)
ACSW_1: J1.12, R22.1, U4.22 (PB11/I2C2_SDA/TIM2_CH4/TSC_G6_IO1/USART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)
ACSW_2: J2.7, R23.1, U4.18 (PB0/ADC_IN8/TIM1_CH2N/TIM3_CH3/TSC_G3_I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)
AIN_ATS: C13.1, R7.1, R19.2, U1.3 (DE), U4.11 (ADC_IN1/COMP1_INP/TIM15_CH1N/TIM2_CH2/T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)
AIN_A_D: C3.1, J1.2, J9.4, R1.2, R7.2
AIN_FB1: C11.1, J1.6, J9.1, R9.2, U4.15 (ADC_IN5/CEC/COMP1_INM/COMP2_INM/DAC_OUT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)
AIN_FB2: C12.1, J1.7, R11.2, U4.16 (ADC_IN6/COMP1_OUT/I2S1_MCK/SPI1_MISO/TI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)
AIN_KTS: C5.1, J1.3, R3.2, U1.4 (DI), U4.12 (ADC_IN2/COMP2_INM/COMP2_OUT/SYS_WKUP4/T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)
AIN_STS: C9.1, J1.5, R8.2, U4.14 (ADC_IN4/COMP1_INM/COMP2_INM/DAC_OUT1/I2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)
AIN_VTS: C7.1, J1.4, R6.2, U1.1 (RO), U4.13 (ADC_IN3/COMP2_INP/TIM15_CH2/TIM2_CH4/TS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)
CAND: U2.1 (D), U4.46 (PB9/CAN_TX/DAC_EXTI9/I2C1_SDA/I2S2_WS/I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)
CANH: D3.2 (A2), J12.3, J13.3, U2.7 (CANH)
CANL: D3.1 (A1), J12.4, J13.4, U2.6 (CANL)
CANR: U2.4 (R), U4.45 (PB8/CAN_RX/CEC/I2C1_SCL/TIM16_CH1/TSC_S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)
CAN_SUSPEND: R21.1, U4.2 (PC13/RTC_OUT_ALARM/RTC_OUT_CALIB/RTC_TA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)
DIN1: J2.11, R14.2, U4.6 (PF1/RCC_OSC_OUT)
DIN2: J2.10, R12.2, U4.21 (PB10/CEC/I2C2_SCL/I2S2_CK/SPI2_SCK/TIM2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)
DIN3: J2.9, R15.2, U4.20 (PB2/TSC_G3_IO4)
DIN4: J2.8, R13.2, U4.19 (PB1/ADC_IN9/TIM14_CH1/TIM1_CH3N/TIM3_CH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)
DIN_SW_B0_135: J2.15, U4.27 (PB14/I2C2_SDA/I2S2_MCK/SPI2_MISO/TIM15_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)
DIN_SW_B0_246: J2.14, U4.3 (PC14/RCC_OSC32_IN)
DIN_SW_B1_135: J2.16, Q3.1 (G), U4.29 (CRS_SYNC/RCC_MCO/TIM1_CH1/USART1_CK/PA8)
DIN_SW_B1_246: J2.13, U4.4 (PC15/RCC_OSC32_OUT)
DIN_SW_B2_135: J2.17, J18.2, U4.31 (TIM17_BKIN/TIM1_CH3/TSC_G4_IO2/USART1_R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)
DIN_SW_B2_246: J2.12, U4.5 (PF0/CRS_SYNC/RCC_OSC_IN)
DIN_SW_B3_135: J2.18, Q2.1 (G), U4.39 (PB3/I2S1_CK/SPI1_SCK/TIM2_CH2/TSC_G5_IO1)
DOUT_K1_FIRE: J1.19, J11.1, U4.33 (CAN_TX/COMP2_OUT/TIM1_ETR/TSC_G4_IO4/US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)
DOUT_K2_20A: J1.18, J11.2, U4.32 (CAN_RX/COMP1_OUT/TIM1_CH4/TSC_G4_IO3/US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)
DOUT_K3_21: J1.14, U4.26 (PB13/I2C2_SCL/I2S2_CK/SPI2_SCK/TIM1_CH1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)
DOUT_K4_T2: J1.16, J18.1, U4.30 (DAC_EXTI9/TIM15_BKIN/TIM1_CH2/TSC_G4_IO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)
DOUT_K5_S3: J1.15, U4.28 (PB15/I2S2_SD/RTC_REFIN/SPI2_MOSI/SYS_WK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)
DOUT_K6_20B: J1.17, R5.1, U4.38 (I2S1_WS/SPI1_NSS/TIM2_CH1/TIM2_ETR/USAR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)
DOUT_LED_RED: J2.6, R4.1, U4.17 (ADC_IN7/COMP2_OUT/I2S1_SD/SPI1_MOSI/TIM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)
DOUT_SW_UKN: J1.13, U4.25 (PB12/I2S2_WS/SPI2_NSS/TIM15_BKIN/TIM1_B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)
GND: C1.2, C2.2, C3.2, C4.2, C5.2, C6.2, C7.2, C8.2, C9.2, C10.2, C11.2, C12.2, C13.2, C14.2, C15.2, D1.1 (K), D2.1 (K), D3.3 (common), D4.2 (A), D5.2 (A), J1.8, J2.1, J2.20, J3.3, J4.1, J5.1, J5.2, J5.3, J5.4, J7.3, J8.2, J9.3, J10.2, J11.3, J12.2, J13.2, J14.2, J14.4, J15.2, J15.4, J17.1, J18.3, Q2.3 (S), Q3.3 (S), Q4.3 (S), Q5.3 (S), R19.1, U1.2 (~RE~), U1.5 (GND), U2.2 (GND), U3.4 (GND), U3.7 (WP), U4.8 (VSSA), U4.23 (VSS), U4.35 (VSS), U4.47 (VSS), U5.2, U6.2
unnamed: C16.1, J16.4, Q7.2 (A2), R20.2
unnamed: C16.2, R29.2
unnamed: C17.1, J16.2, Q6.2 (A2), R24.2
unnamed: C17.2, R26.2
unnamed: D1.2 (A), R4.2
unnamed: D2.2 (A), R5.2
unnamed: D4.1 (K), J15.1, Q4.2 (D)
unnamed: D5.1 (K), J15.3, Q5.2 (D)
unnamed: J4.2, U4.44 (BOOT0)
unnamed: J6.1, R14.1
unnamed: J6.2, R12.1
unnamed: J6.3, R15.1
unnamed: J6.4, R13.1
unnamed: J14.1, Q3.2 (D)
unnamed: J14.3, Q2.2 (D)
unnamed: J16.1, Q6.1 (A1), R25.2, R27.2
unnamed: J16.3, Q7.1 (A1), R28.1, R30.2
unnamed: J17.2, U1.6 (A)
unnamed: J17.3, U1.7 (B)
unnamed: JP1.2, U3.3 (A2)
unnamed: JP2.2, U3.2 (A1)
unnamed: JP3.2, U3.1 (A0)
unnamed: Q1.3 (D), R1.1, R3.1, R6.1, R8.1, R9.1, R11.1
unnamed: Q6.3 (G), R24.1, U5.4
unnamed: Q7.3 (G), R20.1, U6.4
unnamed: R16.2, U4.7 (NRST)
unnamed: R21.2, U2.8 (Rs)
unnamed: R22.2, U5.1
unnamed: R23.2, U6.1
unnamed: R25.1, U5.6
unnamed: R26.1, R27.1
unnamed: R28.2, U6.6
unnamed: R29.1, R30.1
ODSW_1: Q4.1 (G), U4.40 (PB4/I2S1_MCK/SPI1_MISO/TIM17_BKIN/TIM3_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)
ODSW_2: Q5.1 (G), U4.41 (PB5/I2C1_SMBA/I2S1_SD/SPI1_MOSI/SYS_WKU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)
SCL: J8.3, J10.3, R17.2, U3.6 (SCL), U4.42 (PB6/I2C1_SCL/TIM16_CH1N/TSC_G5_IO3/USAR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)
SDA: J8.4, J10.4, R18.2, U3.5 (SDA), U4.43 (PB7/I2C1_SDA/TIM17_CH1N/TSC_G5_IO4/USAR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)
SWDCLK: J7.2, U4.37 (SYS_SWCLK/USART2_TX/PA14)
SWDIO: J7.1, U4.34 (IR_OUT/SYS_SWDIO/USB_OE/PA13)
VCC_18: J2.2, J2.19, R2.2

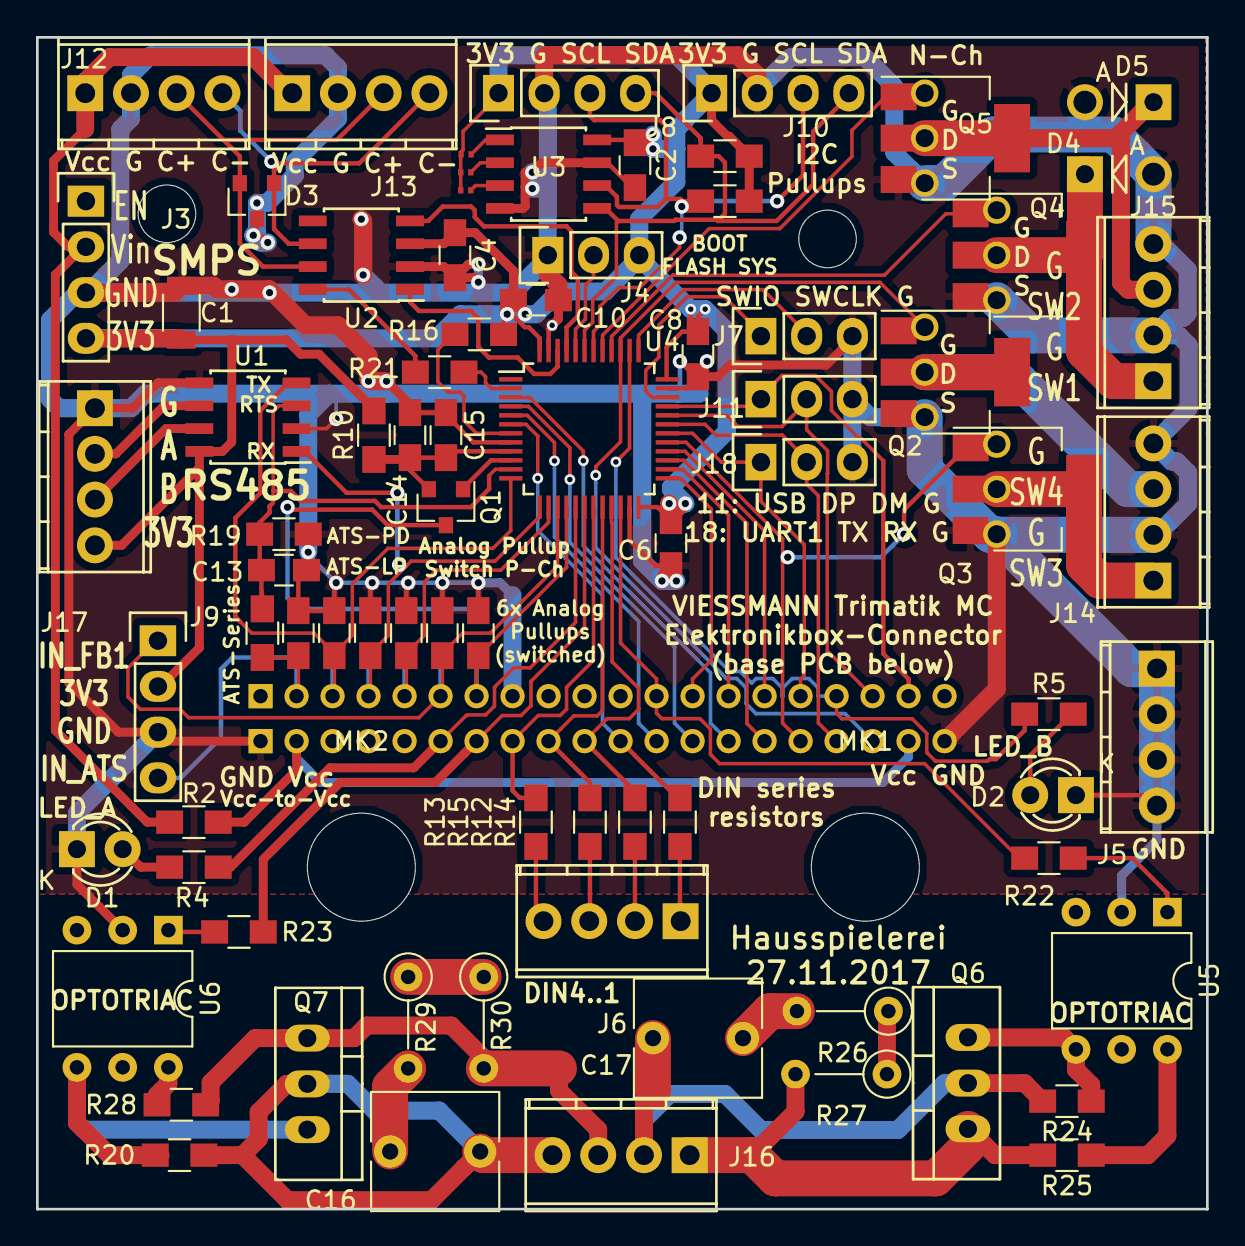
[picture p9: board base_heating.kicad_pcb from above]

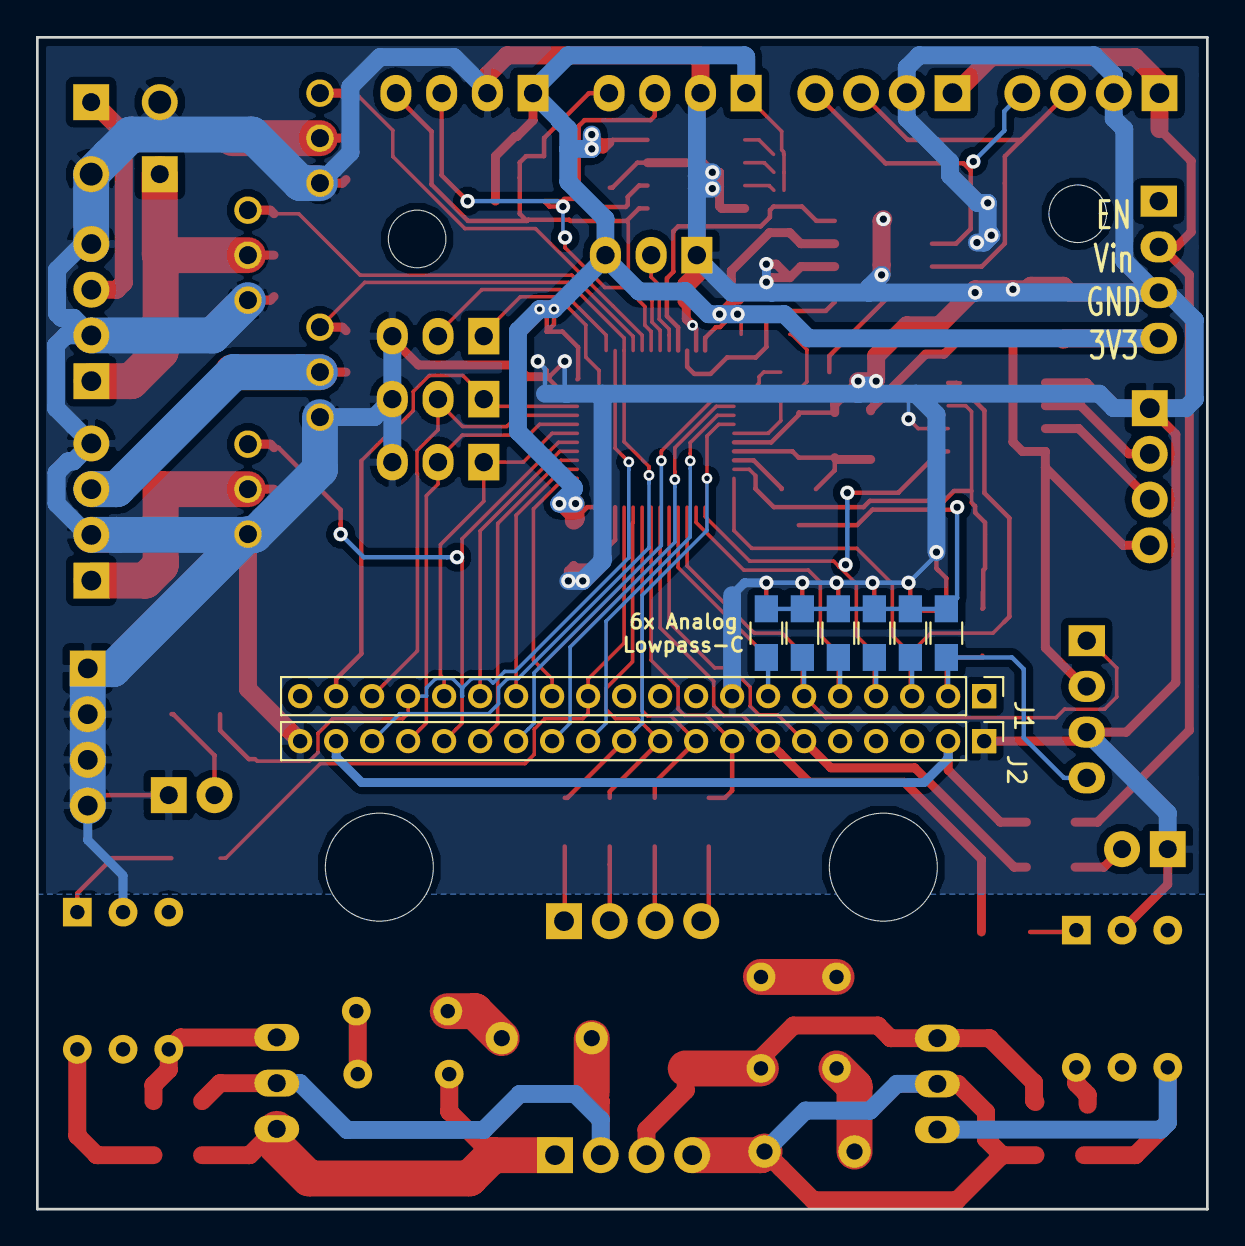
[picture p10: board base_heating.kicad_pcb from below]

Board: 2 copper layers, 65.0 x 65.1 mm, 88 parts (8 on the bottom side), 78 nets.

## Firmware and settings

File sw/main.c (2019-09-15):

/*
 ChibiOS - Copyright (C) 2006..2016 Giovanni Di Sirio

 Licensed under the Apache License, Version 2.0 (the "License");
 you may not use this file except in compliance with the License.
 You may obtain a copy of the License at

 http://www.apache.org/licenses/LICENSE-2.0

 Unless required by applicable law or agreed to in writing, software
 distributed under the License is distributed on an "AS IS" BASIS,
 WITHOUT WARRANTIES OR CONDITIONS OF ANY KIND, either express or implied.
 See the License for the specific language governing permissions and
 limitations under the License.
 */

#include "ch.h"
#include "hal.h"
#include "node.h"
#include "drivers/i2c.h"
#include "config.h"
#include "drivers/analog.h"
#include "dimmer.h"
#include "uavcan.h"
#include "eventcount.h"
#include "util.h"
#include "nodes/node.h"
#include "bootloader_interface.h"
#ifdef BOOTLOADER
#include "bootloader.h"
#endif

static const WDGConfig wdgconfig = {
    7, 0x0FFF, 0x0FFF
};

/*
 * Application entry point.
 */
int main(void)
{

  /*
   * System initializations.
   * - HAL initialization, this also initializes the configured device drivers
   *   and performs the board-specific initializations.
   * - Kernel initialization, the main() function becomes a thread and the
   *   RTOS is active.
   */

  /* Invalidate any bootloader command on application start */
  bootloader_interface.magic = 0;
  halInit();
  chSysInit();
  wdgInit();
  RCC->APB2ENR |= RCC_APB2ENR_DBGMCUEN; //enable MCU debug module clock
  DBGMCU->APB1FZ |= DBGMCU_APB1_FZ_DBG_IWDG_STOP | DBGMCU_APB1_FZ_DBG_WWDG_STOP;
  wdgStart(&WDGD1, &wdgconfig);

  /*
   * Activates the serial driver 2 using the driver default configuration.
   */
  sdStart(&SD1, NULL);
  i2c_init();
  if(config_init(&I2CD1) < 0)
  {
    ERROR("configuration init failed\n");
  }
  node_init();

  wdgReset(&WDGD1);

#ifndef BOOTLOADER
  analog_init();
  dimmer_init();
  wdgReset(&WDGD1);
  app_init();
#endif
  wdgReset(&WDGD1);
  node_setMode(UAVCAN_NODE_MODE_OPERATIONAL);
  /*
   * Normal main() thread activity, in this demo it does nothing except
   * sleeping in a loop and check the button state.
   */
  while (true)
  {
    chThdSleepMilliseconds(500);
  }
}

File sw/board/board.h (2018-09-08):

/*
 * board.h
 *
 *  Created on: 13.01.2018
 *      Author: matthias
 */

#ifndef BOARD_BOARD_H_
#define BOARD_BOARD_H_

#define BOARD_NAME                  "Hausspielerei Trimatik MC base board"

#define STM32_LSECLK                0U
#define STM32_LSEDRV                (3U << 3U)
#define STM32_HSECLK                0U


/*
 * MCU type as defined in the ST header.
 */
#define STM32F072xB

#define GPIOA_PU_OFF                0U
#define GPIOA_ATS                   1U
#define GPIOA_UART2_RTS             1U
#define GPIOA_UART2_DE              1U
#define GPIOA_KTS                   2U
#define GPIOA_UART2_TX              2U
#define GPIOA_VTS                   3U
#define GPIOA_UART2_RX              3U
#define GPIOA_STS                   4U
#define GPIOA_FB1                   5U
#define GPIOA_DIN5                  5U
#define GPIOA_FB2                   6U
#define GPIOA_LED_A                 7U
#define GPIOA_LED_RED               7U
#define GPIOA_ODSW3                 8U
#define GPIOA_SW_B1_135             8U
#define GPIOA_UART1_TX              9U
#define GPIOA_K4_T2                 9U
#define GPIOA_UART1_RX              10U
#define GPIOA_SW_B2_135             10U
#define GPIOA_USB_DM                11U
#define GPIOA_K2_20A                11U
#define GPIOA_USB_DP                12U
#define GPIOA_K1_FIRE               12U
#define GPIOA_SWDIO                 13U
#define GPIOA_SWDCLK                14U
#define GPIOA_LED_B                 15U
#define GPIOA_K6_20B                15U

#define GPIOB_LED_GREEN             0U
#define GPIOB_ACSW2                 0U
#define GPIOB_DIN4                  1U
#define GPIOB_SW_C12                1U
#define GPIOB_DIN3                  2U
#define GPIOB_SW_C34                2U
#define GPIOB_ODSW4                 3U
#define GPIOB_SW_B3_135             3U
#define GPIOB_ODSW1                 4U
#define GPIOB_ODSW2                 5U
#define GPIOB_I2C1_SCL              6U
#define GPIOB_I2C1_SDA              7U
#define GPIOB_CANR                  8U
#define GPIOB_CAND                  9U
#define GPIOB_DIN2                  10U
#define GPIOB_SW_C56                10U
#define GPIOB_ACSW1                 11U
#define GPIOB_SENSE                 11U
#define GPIOB_SW_UKN                12U
#define GPIOB_K3_21                 13U
#define GPIOB_SW_B0_135             14U
#define GPIOB_K5_S3                 15U

#define GPIOC_PIN0                  0U
#define GPIOC_PIN1                  1U
#define GPIOC_PIN2                  2U
#define GPIOC_PIN3                  3U
#define GPIOC_PIN4                  4U
#define GPIOC_PIN5                  5U
#define GPIOC_PIN6                  6U
#define GPIOC_PIN7                  7U
#define GPIOC_PIN8                  8U
#define GPIOC_PIN9                  9U
#define GPIOC_PIN10                 10U
#define GPIOC_PIN11                 11U
#define GPIOC_PIN12                 12U
#define GPIOC_CAN_SUSPEND           13U
#define GPIOC_SW_B0_246             14U
#define GPIOC_SW_B1_246             15U

#define GPIOD_PIN0                  0U
#define GPIOD_PIN1                  1U
#define GPIOD_PIN2                  2U
#define GPIOD_PIN3                  3U
#define GPIOD_PIN4                  4U
#define GPIOD_PIN5                  5U
#define GPIOD_PIN6                  6U
#define GPIOD_PIN7                  7U
#define GPIOD_PIN8                  8U
#define GPIOD_PIN9                  9U
#define GPIOD_PIN10                 10U
#define GPIOD_PIN11                 11U
#define GPIOD_PIN12                 12U
#define GPIOD_PIN13                 13U
#define GPIOD_PIN14                 14U
#define GPIOD_PIN15                 15U

#define GPIOE_PIN0                  0U
#define GPIOE_PIN1                  1U
#define GPIOE_PIN2                  2U
#define GPIOE_PIN3                  3U
#define GPIOE_PIN4                  4U
#define GPIOE_PIN5                  5U
#define GPIOE_PIN6                  6U
#define GPIOE_PIN7                  7U
#define GPIOE_PIN8                  8U
#define GPIOE_PIN9                  9U
#define GPIOE_PIN10                 10U
#define GPIOE_PIN11                 11U
#define GPIOE_PIN12                 12U
#define GPIOE_PIN13                 13U
#define GPIOE_PIN14                 14U
#define GPIOE_PIN15                 15U

#define GPIOF_SW_B2_246             0U
#define GPIOF_SW_B3_246             1U
#define GPIOF_DIN1                  1U
#define GPIOF_PIN2                  2U
#define GPIOF_PIN3                  3U
#define GPIOF_PIN4                  4U
#define GPIOF_PIN5                  5U
#define GPIOF_PIN6                  6U
#define GPIOF_PIN7                  7U
#define GPIOF_PIN8                  8U
#define GPIOF_PIN9                  9U
#define GPIOF_PIN10                 10U
#define GPIOF_PIN11                 11U
#define GPIOF_PIN12                 12U
#define GPIOF_PIN13                 13U
#define GPIOF_PIN14                 14U
#define GPIOF_PIN15                 15U
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

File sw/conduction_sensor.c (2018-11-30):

/*
 * conduction_sensor.c
 *
 *  Created on: 30.01.2018
 *      Author: matthias
 */
#include <stdint.h>
#include "util.h"
#include "drivers/analog.h"
#include "config.h"
#include "qfplib.h"
#include "conduction_sensor.h"

#define CONDUCTION_SENSOR_1_PORT GPIOB
#define CONDUCTION_SENSOR_1_PIN GPIOB_DIN3

#define CONDUCTION_SENSOR_2_PORT GPIOB
#define CONDUCTION_SENSOR_2_PIN GPIOB_DIN2

#define CONDUCTION_SENSOR_COMMON_PORT GPIOB
#define CONDUCTION_SENSOR_COMMON_PIN GPIOB_DIN4
#define CONDUCTION_SENSOR_COMMON_ANALOG_CH 9

#define CONDUCTION_THRESHOLD 200

#define CONDUCTION_MAX_SENSORS 2

static uint16_t SensorRaw[CONDUCTION_MAX_SENSORS];
static uint8_t SensorRefPolarity;
static uint8_t error;
static uint8_t conduction_present_num;
MUTEX_DECL(conductionSensorDataMtx);

void conduction_init(void)
{
  conduction_present_num = config_get_uint(CONFIG_HAS_ANALOG_CONDUCTION_SENSOR);
  if(conduction_present_num) {
    /* Conduction sensor at DIN4 (AIN) vs DIN3/DIN2.
     * should be driven with alternating current to avoid electrolysis.
     * Init: All lines to same level to avoid any current flow
     */
    palSetPadMode(CONDUCTION_SENSOR_1_PORT, CONDUCTION_SENSOR_1_PIN, PAL_MODE_INPUT_PULLUP);
    palSetPadMode(CONDUCTION_SENSOR_2_PORT, CONDUCTION_SENSOR_2_PIN, PAL_MODE_INPUT_PULLUP);
    palSetPadMode(CONDUCTION_SENSOR_COMMON_PORT, CONDUCTION_SENSOR_COMMON_PIN, PAL_MODE_INPUT_PULLUP);
    if(conduction_present_num > CONDUCTION_MAX_SENSORS)
    {
      conduction_present_num = CONDUCTION_MAX_SENSORS;
    }
  }
  /* initialize data to realworld situation :-) */
  conduction_acquire();
}

/* checks v to be an acceptable reference for polarity.
 * Sets a global error state if failed.
 */
static void checkReferenceLevel(uint16_t v, uint8_t polarity)
{
  if((polarity && v < (ANALOG_MAX / 16) * 11)
      || (!polarity && v > (ANALOG_MAX / 16) * 5))
  {
    error = 1;
  }
}

void conduction_acquire(void)
{
  /* polarity defines low(0) or high(1) on common port side */
  static uint8_t polarity = 1;
  uint16_t ref;
  iomode_t passive_mode = PAL_MODE_INPUT_ANALOG;
  iomode_t input_mode = polarity ? PAL_MODE_INPUT_PULLUP : PAL_MODE_INPUT_PULLDOWN;

  chMtxLock(&conductionSensorDataMtx);
  palSetPadMode(CONDUCTION_SENSOR_COMMON_PORT, CONDUCTION_SENSOR_COMMON_PIN, input_mode);

  /* first measure reference (open connection) */
  palSetPadMode(CONDUCTION_SENSOR_2_PORT, CONDUCTION_SENSOR_2_PIN, passive_mode);
  palSetPadMode(CONDUCTION_SENSOR_1_PORT, CONDUCTION_SENSOR_1_PIN, passive_mode);
  chThdSleep(TIME_MS2I(1));
  analog_filter_reset(1 << CONDUCTION_SENSOR_COMMON_ANALOG_CH);
  chThdSleep(TIME_MS2I(5));
  ref = adc_smp_filtered[CONDUCTION_SENSOR_COMMON_ANALOG_CH];
  checkReferenceLevel(ref, polarity);

  /* first measure sensor 1 */
  palSetPadMode(CONDUCTION_SENSOR_2_PORT, CONDUCTION_SENSOR_2_PIN, passive_mode);
  palSetPadMode(CONDUCTION_SENSOR_1_PORT, CONDUCTION_SENSOR_1_PIN, PAL_MODE_OUTPUT_PUSHPULL);
  if(polarity)
  {
    palClearPad(CONDUCTION_SENSOR_1_PORT, CONDUCTION_SENSOR_1_PIN);
  } else
  {
    palSetPad(CONDUCTION_SENSOR_1_PORT, CONDUCTION_SENSOR_1_PIN);
  }
  chThdSleep(TIME_MS2I(1));
  analog_filter_reset(1 << CONDUCTION_SENSOR_COMMON_ANALOG_CH);
  chThdSleep(TIME_MS2I(5));
  SensorRaw[0] = adc_smp_filtered[CONDUCTION_SENSOR_COMMON_ANALOG_CH];

  /* then measure sensor 2 */
  palSetPadMode(CONDUCTION_SENSOR_1_PORT, CONDUCTION_SENSOR_1_PIN, passive_mode);
  palSetPadMode(CONDUCTION_SENSOR_2_PORT, CONDUCTION_SENSOR_2_PIN, PAL_MODE_OUTPUT_PUSHPULL);
  if(polarity)
  {
    palClearPad(CONDUCTION_SENSOR_2_PORT, CONDUCTION_SENSOR_2_PIN);
  } else
  {
    palSetPad(CONDUCTION_SENSOR_2_PORT, CONDUCTION_SENSOR_2_PIN);
  }
  chThdSleep(TIME_MS2I(1));
  analog_filter_reset(1 << CONDUCTION_SENSOR_COMMON_ANALOG_CH);
  chThdSleep(TIME_MS2I(5));
  SensorRaw[1] = adc_smp_filtered[CONDUCTION_SENSOR_COMMON_ANALOG_CH];

  /* measure reference again to detect errors */
  palSetPadMode(CONDUCTION_SENSOR_2_PORT, CONDUCTION_SENSOR_2_PIN, passive_mode);
  palSetPadMode(CONDUCTION_SENSOR_1_PORT, CONDUCTION_SENSOR_1_PIN, passive_mode);
  chThdSleep(TIME_MS2I(1));
  analog_filter_reset(1 << CONDUCTION_SENSOR_COMMON_ANALOG_CH);
  chThdSleep(TIME_MS2I(5));
  ref = adc_smp_filtered[CONDUCTION_SENSOR_COMMON_ANALOG_CH];
  checkReferenceLevel(ref, polarity);

  SensorRefPolarity = polarity;
  /* finally, passivate & change polarity */
  palSetPadMode(CONDUCTION_SENSOR_COMMON_PORT, CONDUCTION_SENSOR_COMMON_PIN, passive_mode);
  palSetPadMode(CONDUCTION_SENSOR_1_PORT, CONDUCTION_SENSOR_1_PIN, passive_mode);
  palSetPadMode(CONDUCTION_SENSOR_2_PORT, CONDUCTION_SENSOR_2_PIN, passive_mode);
  polarity = !polarity;
  chMtxUnlock(&conductionSensorDataMtx);
}

uint8_t conduction_getClearError(void)
{
  uint8_t e = error;
  error = 0;
  return e;
}


bool conduction_evaluate(uint8_t sensor, uint8_t *quality)
{
  chMtxLock(&conductionSensorDataMtx);
  float raw = qfp_int2float(SensorRaw[sensor]);
  float v = qfp_fdiv(raw, ANALOG_MAX);
  if(SensorRefPolarity) {
    v = qfp_fsub(1.0f, v);
  }
  chMtxUnlock(&conductionSensorDataMtx);

  int q = qfp_float2int(qfp_fmul(255.0f, v));
  if(quality)
  {
    *quality = q;
  }

  return q > CONDUCTION_THRESHOLD;
}

uint8_t conduction_num_sensors(void)
{
  return conduction_present_num;
}

//static void broadcast_conduction_data(uint8_t error, uint8_t state, uint8_t num, uint8_t *quality)
//{
//  uint8_t buffer[HOMEAUTOMATION_CONDUCTION_SENSOR_MESSAGE_SIZE];
//  static uint8_t transfer_id = 0;
//  /* bit0: Error in data */
//  buffer[0] = state; /* Bit 0-6: state */
//  if(error)
//  {
//    buffer[0] |= 0x80; /* Bit 7: error */
//  }
//  for(int i = 0; i < num; ++i) {
//    buffer[1+i] = quality[i];
//  }
//  canardLockBroadcast(&canard,
//          HOMEAUTOMATION_CONDUCTION_SENSOR_DATA_TYPE_SIGNATURE,
//          HOMEAUTOMATION_CONDUCTION_SENSOR_DATA_TYPE_ID, &transfer_id,
//          CANARD_TRANSFER_PRIORITY_LOW, buffer, 1 + num);
//}

///* Conduction sensor */
//    uint8_t num = conduction_num_sensors();
//    if(num)
//    {
//      uint8_t state = 0;
//      uint8_t q[8];
//      conduction_acquire();
//      uint8_t error = conduction_getClearError();
//      for(int i = 0; i < num; ++i)
//      {
//        if(conduction_evaluate(i, &q[i]))
//        {
//          state |= (1 << i);
//        }
//      }
//      broadcast_conduction_data(error, state, num, q);
//    }

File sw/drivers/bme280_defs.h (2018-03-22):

/**
 * Copyright (C) 2016 - 2017 Bosch Sensortec GmbH
 *
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
 * Redistributions of source code must retain the above copyright
 * notice, this list of conditions and the following disclaimer.
 *
 * Redistributions in binary form must reproduce the above copyright
 * notice, this list of conditions and the following disclaimer in the
 * documentation and/or other materials provided with the distribution.
 *
 * Neither the name of the copyright holder nor the names of the
 * contributors may be used to endorse or promote products derived from
 * this software without specific prior written permission.
 *
 * THIS SOFTWARE IS PROVIDED BY THE COPYRIGHT HOLDERS AND
 * CONTRIBUTORS "AS IS" AND ANY EXPRESS OR
 * IMPLIED WARRANTIES, INCLUDING, BUT NOT LIMITED TO, THE IMPLIED
 * WARRANTIES OF MERCHANTABILITY AND FITNESS FOR A PARTICULAR PURPOSE ARE
 * DISCLAIMED. IN NO EVENT SHALL COPYRIGHT HOLDER
 * OR CONTRIBUTORS BE LIABLE FOR ANY
 * DIRECT, INDIRECT, INCIDENTAL, SPECIAL, EXEMPLARY,
 * OR CONSEQUENTIAL DAMAGES(INCLUDING, BUT NOT LIMITED TO,
 * PROCUREMENT OF SUBSTITUTE GOODS OR SERVICES;
 * LOSS OF USE, DATA, OR PROFITS; OR BUSINESS INTERRUPTION)
 * HOWEVER CAUSED AND ON ANY THEORY OF LIABILITY,
 * WHETHER IN CONTRACT, STRICT LIABILITY, OR TORT
 * (INCLUDING NEGLIGENCE OR OTHERWISE) ARISING IN
 * ANY WAY OUT OF THE USE OF THIS
 * SOFTWARE, EVEN IF ADVISED OF THE POSSIBILITY OF SUCH DAMAGE
 *
 * The information provided is believed to be accurate and reliable.
 * The copyright holder assumes no responsibility
 * for the consequences of use
 * of such information nor for any infringement of patents or
 * other rights of third parties which may result from its use.
 * No license is granted by implication or otherwise under any patent or
 * patent rights of the copyright holder.
 *
 * @file	bme280_defs.h
 * @date	22 Nov 2017
 * @version	3.3.2
 * @brief
 *
 */

/*! @file bme280_defs.h
    @brief Sensor driver for BME280 sensor */
/*!
 * @defgroup BME280 SENSOR API
 * @brief
 * @{*/
#ifndef BME280_DEFS_H_
#define BME280_DEFS_H_

/********************************************************/
/* header includes */
#ifdef __KERNEL__
#include <linux/types.h>
#include <linux/kernel.h>
#else
#include <stdint.h>
#include <stddef.h>
#endif

/********************************************************/
/*! @name		Common macros		        */
/********************************************************/

#if !defined(UINT8_C) && !defined(INT8_C)
#define INT8_C(x)       S8_C(x)
#define UINT8_C(x)      U8_C(x)
#endif

#if !defined(UINT16_C) && !defined(INT16_C)
#define INT16_C(x)      S16_C(x)
#define UINT16_C(x)     U16_C(x)
#endif

#if !defined(INT32_C) && !defined(UINT32_C)
#define INT32_C(x)      S32_C(x)
#define UINT32_C(x)     U32_C(x)
#endif

#if !defined(INT64_C) && !defined(UINT64_C)
#define INT64_C(x)      S64_C(x)
#define UINT64_C(x)     U64_C(x)
#endif

/**@}*/

/**\name C standard macros */
#ifndef NULL
#ifdef __cplusplus
#define NULL   0
#else
#define NULL   ((void *) 0)
#endif
#endif
/********************************************************/

#ifndef BME280_FLOAT_ENABLE
/* #define BME280_FLOAT_ENABLE */
#endif

#ifndef BME280_FLOAT_ENABLE
#ifndef BME280_64BIT_ENABLE
//#define BME280_64BIT_ENABLE
#endif
#endif

#ifndef TRUE
#define TRUE                UINT8_C(1)
#endif
#ifndef FALSE
#define FALSE               UINT8_C(0)
#endif

/**\name I2C addresses */
#define BME280_I2C_ADDR_PRIM	UINT8_C(0x76)
#define BME280_I2C_ADDR_SEC		UINT8_C(0x77)

/**\name BME280 chip identifier */
#define BME280_CHIP_ID  UINT8_C(0x60)
#define BMP280_CHIP_ID1 UINT8_C(0x56)
#define BMP280_CHIP_ID2 UINT8_C(0x57)
#define BMP280_CHIP_ID3 UINT8_C(0x58)
/**\name Register Address */
#define BME280_CHIP_ID_ADDR					UINT8_C(0xD0)
#define BME280_RESET_ADDR					UINT8_C(0xE0)
#define BME280_TEMP_PRESS_CALIB_DATA_ADDR	UINT8_C(0x88)
#define BME280_HUMIDITY_CALIB_DATA_ADDR		UINT8_C(0xE1)
#define BME280_PWR_CTRL_ADDR				UINT8_C(0xF4)
#define BME280_CTRL_HUM_ADDR				UINT8_C(0xF2)
#define BME280_CTRL_MEAS_ADDR				UINT8_C(0xF4)
#define BME280_CONFIG_ADDR					UINT8_C(0xF5)
#define BME280_DATA_ADDR					UINT8_C(0xF7)

/**\name API success code */
#define BME280_OK					INT8_C(0)

/**\name API error codes */
#define BME280_E_NULL_PTR			INT8_C(-1)
#define BME280_E_DEV_NOT_FOUND		INT8_C(-2)
#define BME280_E_INVALID_LEN		INT8_C(-3)
#define BME280_E_COMM_FAIL			INT8_C(-4)
#define BME280_E_SLEEP_MODE_FAIL	INT8_C(-5)

/**\name API warning codes */
#define BME280_W_INVALID_OSR_MACRO      INT8_C(1)

/**\name Macros related to size */
#define BME280_TEMP_PRESS_CALIB_DATA_LEN	UINT8_C(26)
#define BME280_HUMIDITY_CALIB_DATA_LEN		UINT8_C(7)
#define BME280_P_T_H_DATA_LEN				UINT8_C(8)

/**\name Sensor power modes */
#define	BME280_SLEEP_MODE		UINT8_C(0x00)
#define	BME280_FORCED_MODE		UINT8_C(0x01)
#define	BME280_NORMAL_MODE		UINT8_C(0x03)

/**\name Macro to combine two 8 bit data's to form a 16 bit data */
#define BME280_CONCAT_BYTES(msb, lsb)     (((uint16_t)msb << 8) | (uint16_t)lsb)
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

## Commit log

2017-11-24 Initial commit
    schematics design/pcb is preliminary POC to discuss the concept
    [base_heating.kicad_pcb, base_heating.sch]
2017-11-27 Finished schematics, updated screenshot
    [base_heating.kicad_pcb, base_heating.sch]
2017-11-28 Update PCB to fabricated version
    [base_heating.kicad_pcb]
2017-11-28 Document pin assignments and some software ideas
2017-12-03 Add STM32F072 Example as base code
2017-12-03 Add customized board configuration based on NUCLEO
2017-12-03 Fix main using removed module
    [main.c]
2017-12-04 Update libuavcan for STM32F0XX
2018-01-13 Add chibios stm32f072 demo
2018-01-13 Add board definition, build libcanard
2018-01-14 Correctly enable CAN driver, increase buffers
    This is the first version that was actually observed working on the
    hardware.
    [halconf.h, node.c]
2018-01-22 Simpler microsecond timing for can frames
2018-01-22 Add BME280 environment sensor
2018-01-22 Use ChibiOs CAN driver instead of canard_stm32
2018-01-23 Add flash erase/program driver
2018-01-23 Use CAN thread for sending all messages
2018-01-24 EEPROM driver, i2c fixes
    [eeprom24c.c, i2c.c]
2018-01-27 Fix I2C initialization and EEPROM write
    [eeprom24c.c, i2c.c, main.c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]
2018-01-27 Fix eeprom write only once
    [eeprom24c.c]
2018-01-28 various fixes
    more debugging,
    do not fail on broken EEPROM content
    This bootloader has been successfully used on a bunch of boards
    [eeprom24c.c]
2018-01-29 Read analog inputs, broadcast temperature
2018-01-29 Enable WFI idle for power saving
2018-01-30 WIP pump control
2018-01-30 WIP conduction sensor driver
    Also include qfplib for floating point and refactor analog driver
2018-02-01 Multithread canard RX/TX, cleanup conduction sensor
2018-02-03 Implementet pump and conduction sensor
    This version is running (as of now) on the grey water buffer and
    confirmed working pump control :)
2018-03-12 Add Minipcb
    [ios.sch, stm32f0-can-mini-breakout.kicad_pcb, stm32f0-can-mini-breakout.sch]
2018-03-12 update pcb
    [stm32f0-can-mini-breakout.kicad_pcb]
2018-04-02 Conduction sensor threshold for aged sensors
2018-04-09 fix baudrate for sml
    [halconf.h, node.c]
2018-04-13 untested pump receiver
2018-04-13 Add PWM driver as framework for light controller
2018-04-14 fix & improve pumpreceiver
    [node.c, uavcan.h]
2018-04-14 Fix bootloader compilation, increase application flash size
    [node.c]
2018-04-14 update conduction sensor threshold
2018-04-14 Initialize PWM pins
2018-04-20 improve pwm spectrum & brightness
2018-04-20 Fix motion sensor, FadeIn on hallway
    [light.c, node.c]
2018-04-22 fix motion sensor timing & fading
    [light.c]
2018-05-03 enable light switch
    does not work yet, have to find correct input pin
    [light.c]
2018-05-04 disable hallway switch again
2018-05-16 add new greywater pump control
2018-05-28 make conduction sensor more sensitive
    pump PWM does not work for unknown reason, is always on. so it now switches to refill only when it detects that the bottom tank is empty
    [conduction_sensor.c]
2018-05-30 pump: remove PWM, add slow IIR and hysteresis
2018-09-07 triac pcb errata
2018-09-08 Initial viessmann_trimatik node
    just debugs keys and temperatures
2018-09-08 Fix analog input pullups, analog filter reset
    [analog.c, board.h, conduction_sensor.c]
2018-09-08 Update kicad board
    [base_heating.sch]
2018-10-20 Add heating status type and debug broadcast
2018-10-24 better rounding in analog filter
2018-10-24 Include basic heating curve calculation
    WIP intermediate conversions not yet implemented/right
2018-11-04 implement basic heating control
2018-11-11 Implement heating times
    currently, just two different times can be used by defining start/end
    times and relative temperature offsets.
2018-11-21 Cycle extension as flow temperature optimisation
2018-11-21 Fix heating system starting with burner stop phase
2018-11-25 Heating node: try to match target flow better
2018-11-30 Implement bathroom fan control
    first implementation of dew point / wall condensation detection.
    To be abstracted and reused :-)
2018-12-01 Enable fan control, better timeouts for occupancy
2018-12-01 Fix mistake on switching fan pins
2018-12-06 Modularize further, changes to fan/door handling
2019-01-08 Light switch implementation
2019-08-31 use bathroom brightness sensor for hallway light control
2019-08-31 Add boiler node (WIP)
    including PID controller and obis listener
2019-09-01 Fix PID, add some debug
2019-09-02 Boiler control based on 1.8.0/2.8.0 power
2019-09-10 Boiler status receiver, max temperature
2019-09-10 different target power regulation
2019-11-03 mini pcb v2
    [ios.sch, stm32f0-can-mini-breakout.kicad_pcb, stm32f0-can-mini-breakout.sch]
2019-11-03 Boiler min temperature
2019-11-05 Improve 230V isolation and mounting spcae
2019-11-05 hub pcb
    [hub.kicad_pcb, hub.sch]
2019-11-17 I controller for flow temperature
2019-11-17 update v2pcb
    [stm32f0-can-mini-breakout.kicad_pcb]
2019-11-23 Add missing files for pcbs
2020-05-31 remove unused current_power
2020-05-31 add boiler target temperature
2020-06-06 add motion sensor status
2020-06-06 remove debug print
2020-06-18 hallway light: detect motion sensor level, not edge
2021-01-11 limit flow deviation integral, use exponential algorithm

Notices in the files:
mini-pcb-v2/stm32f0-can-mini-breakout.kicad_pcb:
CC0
